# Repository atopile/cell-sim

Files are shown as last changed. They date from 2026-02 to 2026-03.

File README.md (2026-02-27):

# CellSim v2

Modular, rack-mountable battery cell simulator for BMS development and testing.

**Status:** In development — see [`docs/cellsim-v2-spec.md`](docs/cellsim-v2-spec.md) for the full specification.

## Overview

CellSim v2 uses a **backplane + card architecture**: a base board with a Raspberry Pi CM5 controller and gigabit Ethernet switch connects to up to ~20 plug-in cards, each carrying an STM32H723 MCU and 8 isolated cell channels.

### Key Specs (per channel)

| Parameter | Target |
|---|---|
| Output voltage | 0 – 6 V |
| Output current | 0 – 1 A |
| Voltage accuracy | ±1 mV (after calibration) |
| Update rate | 100 Hz |
| Kelvin sensing | Force + Sense, 2-wire/4-wire selectable |

### Card Types

- **Cell Card** — 8 isolated cell channels with Kelvin output
- **Thermistor Card** — 8 thermistor/NTC emulation channels
- Same backplane connector and form factor for both

## Repository Structure

```
elec/
  cell-card/      # Cell card electronics (base-card + cell/thermistor modules)
  backplane/      # Base board electronics (CM5, switches, power, fans)
  packages/       # Custom atopile packages (e.g. ADS1219)
firmware/
  card/           # Zephyr RTOS firmware for STM32H723 card MCU
software/
  src/cellsim/    # CM5 orchestration server (FastAPI) + Python client
mechanical/       # Enclosure, rack mount hardware
docs/             # Specification, diagrams
```

## Architecture

```
                    ┌─────────────────────────────────┐
                    │          Base Board              │
  Ethernet ────────►│  CM5  ──RGMII──►  RTL8305NB x5  │
  (uplink)          │  eth0            (cascaded GbE)  │
                    └──────────┬──────────────────────┘
                               │ 100M per port
               ┌───────────────┼───────────────┐
               ▼               ▼               ▼
         ┌──────────┐   ┌──────────┐   ┌──────────┐
         │ Card #0  │   │ Card #1  │   │ Card #N  │
         │ STM32H723│   │ STM32H723│   │ STM32H723│
         │ 8 cells  │   │ 8 cells  │   │ 8 cells  │
         └──────────┘   └──────────┘   └──────────┘
```

## Development

### Electronics (atopile)

The hardware is designed using [atopile](https://atopile.io/). Each board has its own `ato.yaml` build manifest.

### Firmware (Zephyr)

Card firmware uses [Zephyr RTOS](https://zephyrproject.org/) targeting the STM32H723. Development board: Nucleo-H723ZG.

### Software (Python)

The CM5 orchestration server is a FastAPI application. Install for development:

```bash
cd software
pip install -e ".[dev]"
cellsim  # starts the server on port 8000
```

## License

See [LICENSE](LICENSE).

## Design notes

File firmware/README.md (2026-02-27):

# CellSim Card Firmware

Zephyr RTOS firmware for the CellSim v2 cell card (STM32H723 + LAN8742A).

Each card manages 8 battery cell simulation channels. Cards communicate with a
central CM5 compute module over Ethernet: TCP for commands, UDP for 100 Hz
measurement streaming, mDNS for discovery.

## Prerequisites

- **Podman** (or Docker) — the entire toolchain runs in a container
- ~10 GB disk space for the Zephyr workspace (downloaded once, cached in a volume)

```bash
# Fedora / RHEL
sudo dnf install podman

# Ubuntu / Debian
sudo apt install podman

# Or use Docker — set CONTAINER_RT=docker in make commands
```

## Quick Start

```bash
cd firmware/

# First time: pull image + initialize west workspace (~5 min)
make setup

# Build firmware
make build
```

The output binary is at `build/zephyr/zephyr.bin`.

## Build Commands

| Command | Description |
|---|---|
| `make setup` | Pull Zephyr image + init west workspace (first time) |
| `make build` | Build firmware for nucleo_h723zg |
| `make clean` | Remove build artifacts |
| `make shell` | Interactive shell inside the build container |
| `make menuconfig` | Run Zephyr menuconfig (TUI Kconfig editor) |
| `make flash` | Flash via ST-Link (requires ST-Link on host) |
| `make help` | Show available targets |

Override the board: `make build BOARD=stm32h723zg_custom`

Use Docker instead of Podman: `make build CONTAINER_RT=docker`

## Project Structure

```
firmware/
├── Makefile                  # Build system (this file)
├── west.yml                  # West manifest — pins Zephyr v4.0.0
├── README.md                 # This file
├── build/                    # Build output (gitignored)
└── card/                     # Application source
    ├── CMakeLists.txt        # CMake build definition
    ├── prj.conf              # Zephyr Kconfig
    ├── boards/
    │   └── nucleo_h723zg.overlay  # Device tree overlay
    └── src/
        ├── main.c            # Entry point, slot ID, init sequence
        ├── network.c/.h      # TCP command server, UDP streaming, mDNS
        ├── self_test.c/.h    # Per-cell BIST (I2C probe, temp check)
        ├── watchdog.c/.h     # IWDG + CM5 heartbeat monitor
        └── health.c/.h       # MCU temp, Vrefint, input voltage (ADC3)
```

## Architecture

```
┌──────────────────────────────────────────────┐
│  main.c                                      │
│  ├─ read_slot_id()         GPIO decode       │
│  ├─ health_init()          ADC3 setup        │
│  ├─ watchdog_init()        IWDG + heartbeat  │
│  ├─ self_test_run()        I2C BIST all 8    │
│  └─ network_init()         mDNS + sockets    │
│       ├─ TCP cmd server    (thread, pri 7)   │
│       └─ UDP meas stream   (thread, pri 3)   │
│           └─ 100 Hz loop: ADC → pack → send  │
│              └─ watchdog_feed() per tick      │
└──────────────────────────────────────────────┘

I2C topology:
  I2C1 → TCA9548A → [ISO1640 → cell devices] × 4  (cells 0–3)
  I2C2 → TCA9548A → [ISO1640 → cell devices] × 4  (cells 4–7)

Per-cell devices (isolated side):
  MCP4725 ×2 (DAC: buck + LDO setpoint)
  ADS1219    (ADC: voltage + current)
  TCA6408    (GPIO: relay, enable, load switch)
  TMP117     (temperature)
```

## Configuration

### Kconfig (`card/prj.conf`)

Key options:
- `CONFIG_NET_DHCPV4=y` — DHCP for IP assignment
- `CONFIG_MDNS_RESPONDER=y` — mDNS advertisement
- `CONFIG_WATCHDOG=y` — Hardware IWDG
- MCUboot/MCUmgr options are commented out for initial builds

Edit interactively: `make menuconfig`

### Device Tree Overlay (`card/boards/nucleo_h723zg.overlay`)

Defines I2C buses, UART, ADC, watchdog, and Ethernet for the card PCB.
Pin assignments are placeholders pending final PCB layout.

### West Manifest (`west.yml`)

Pins Zephyr v4.0.0 with only the modules needed:
- `hal_stm32` — STM32H7 HAL
- `cmsis` — ARM CMSIS headers
- `mbedtls` — TLS stack
- `mcuboot` — Bootloader (for later OTA)
- `net-tools` — Networking utilities

## Flashing

### ST-Link (development)

Connect ST-Link to the card's SWD header, then:

```bash
make flash
```

### UART Bootloader (production — via CM5)

The CM5 can flash cards remotely using the STM32 ROM bootloader (AN3155):

1. CM5 selects the card via slot mux (CD74HC4067SM)
2. Asserts BOOT0 high + pulses NRST
3. Streams firmware over UART using the AN3155 protocol
4. Releases BOOT0, pulses NRST to boot into new firmware

### DFU over USB (if available)

```bash
dfu-util -a 0 -s 0x08000000 -D build/zephyr/zephyr.bin
```

## Troubleshooting

**`make setup` fails with permission error**
Podman's rootless mode needs `--userns=keep-id`. If you're using Docker, set
`CONTAINER_RT=docker`.

**`west update` hangs or fails**
The Zephyr tree is large. Ensure you have a stable internet connection.
The `--narrow -o=--depth=1` flags minimize download size.

**Build fails with "Zephyr not found"**
Run `make setup` first. The west workspace must be initialized before building.

**`CONFIG_ETH_STM32_HAL` warning**
If Zephyr renames this symbol, check `make menuconfig` under
Drivers → Ethernet for the current name.

**Flash fails: "No ST-Link detected"**
- Ensure the ST-Link is connected and powered
- Check `lsusb` for the ST-Link device
- The `--privileged` flag and `/dev/bus/usb` mount are needed for USB access

## Adapting for Other Projects

1. Copy `firmware/` to your project
2. Edit `west.yml` to add/remove Zephyr modules
3. Replace `card/` with your application
4. Update `BOARD` in the Makefile
5. Run `make setup && make build`

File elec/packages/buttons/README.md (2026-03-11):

# Buttons - Momentary Switches

Simple momentary switches that can be used to bridge connections in circuits.

## Usage

```ato
#pragma experiment("BRIDGE_CONNECT")
#pragma experiment("FOR_LOOP")

import Electrical
import ElectricPower
import Resistor

from "atopile/buttons/buttons.ato" import VerticalButton
from "atopile/buttons/buttons.ato" import HorizontalButton

module Usage:
    """
    Examples showing different ways to use buttons:
    1. Simple bridging connections
    2. Pullup configuration (button pulls to ground, resistor pulls to VCC)
    3. Pulldown configuration (button pulls to VCC, resistor pulls to ground)
    """

    # Power supply for pullup/pulldown examples
    power = new ElectricPower

    # === Example 1: Simple bridging ===
    btn_bridge = new VerticalButton
    signal_a = new Electrical
    signal_b = new Electrical

    # When button is pressed, signal_a connects to signal_b
    signal_a ~> btn_bridge ~> signal_b

    # === Example 2: Pullup configuration ===
    # Button pulls signal to ground when pressed, resistor pulls to VCC when released
    btn_pullup = new HorizontalButton
    pullup_resistor = new Resistor
    pullup_signal = new Electrical

    # Configure pullup resistor
    pullup_resistor.resistance = 10kohm +/- 5%
    pullup_resistor.package = "0402"

    # Connections: signal pulled high by resistor, pulled low by button
    power.hv ~> pullup_resistor ~> pullup_signal
    pullup_signal ~> btn_pullup ~> power.lv

    # === Example 3: Pulldown configuration ===
    # Button pulls signal to VCC when pressed, resistor pulls to ground when released
    btn_pulldown = new VerticalButton
    pulldown_resistor = new Resistor
    pulldown_signal = new Electrical

    # Configure pulldown resistor
    pulldown_resistor.resistance = 10kohm +/- 5%
    pulldown_resistor.package = "0402"

    # Connections: signal pulled low by resistor, pulled high by button
    power.lv ~> pulldown_resistor ~> pulldown_signal
    pulldown_signal ~> btn_pulldown ~> power.hv

```

## Contributing

Contributions to this package are welcome via pull requests on the GitHub repository.

## License

This atopile package is provided under the [MIT License](https://opensource.org/license/mit/).

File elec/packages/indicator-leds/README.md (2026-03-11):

# Indicator LEDs (0603) – Red/Green/Blue/Yellow/Yellow-Green/White

Convenience modules for single indicator LEDs with a correctly sized series resistor and bridgeable interface.

## Usage

```ato
#pragma experiment("BRIDGE_CONNECT")

import ElectricPower

from "atopile/indicator-leds/indicator-leds.ato" import LEDIndicatorRed
from "atopile/indicator-leds/indicator-leds.ato" import LEDIndicatorGreen

module Usage:
    """
    Minimal usage example for `indicator-leds`.
    Demonstrates direct power connection and bridge usage.
    """

    red_led = new LEDIndicatorRed
    green_led = new LEDIndicatorGreen

    # Direct power connection
    power = new ElectricPower
    power.voltage = 5V
    power ~ red_led.power
    power ~ green_led.power

```

## Contributing

Contributions are welcome! Feel free to open issues or pull requests.

## License

This package is provided under the [MIT License](https://opensource.org/license/mit/).

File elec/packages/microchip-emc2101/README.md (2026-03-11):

# Microchip EMC2101 Temperature Sensor and Fan Controller

A comprehensive driver for the Microchip EMC2101 temperature monitoring and PWM fan control IC. This package provides a complete atopile implementation for thermal management applications.

## Features

- **Internal Temperature Sensor**: ±2°C accuracy for local temperature monitoring
- **External Temperature Sensing**: Remote diode connection via DP/DN pins for CPU/GPU temperature monitoring
- **PWM Fan Control**: Precise fan speed control via dedicated FAN output pin
- **Tachometer/Alert**: Combined nALERT_TACH pin for thermal alerts and fan speed feedback
- **I2C/SMBus Interface**: Standard 3.3V communication interface (SMCLK/SMDATA)
- **Package**: MSOP-8 surface mount package
- **JLCPCB Part**: C626968 (EMC2101-R-ACZL-TR)

## Pin Configuration (MSOP-8)

1. **VDD** - Power supply (3.0V to 3.6V)
2. **DP** - External diode positive terminal
3. **DN** - External diode negative terminal
4. **FAN** - PWM fan drive output
5. **GND** - Ground
6. **nALERT_TACH** - Alert output / Tachometer input (shared pin)
7. **SMDATA** - I2C/SMBus Data
8. **SMCLK** - I2C/SMBus Clock

## Usage

```ato
#pragma experiment("TRAITS")
#pragma experiment("FOR_LOOP")
#pragma experiment("BRIDGE_CONNECT")

import ElectricLogic
import ElectricPower
import I2C
from "atopile/microchip-emc2101/microchip-emc2101.ato" import Microchip_EMC2101

module Usage:
    """
    Minimal usage example for microchip-emc2101.
    Demonstrates how to use the EMC2101 temperature sensor and fan controller
    in a typical thermal management application with MSOP-8 package.
    """

    # Power supply
    power_3v3 = new ElectricPower
    assert power_3v3.voltage within 3.2V to 3.4V

    # I2C bus for communication
    i2c_bus = new I2C
    assert i2c_bus.frequency within 100kHz to 400kHz

    # Fan control signal
    fan_pwm_signal = new ElectricLogic

    # EMC2101 temperature sensor and fan controller
    temp_controller = new Microchip_EMC2101

    # Connect power
    power_3v3 ~ temp_controller.power

    # Connect I2C bus
    i2c_bus ~ temp_controller.i2c

    # Connect fan PWM output
    fan_pwm_signal ~ temp_controller.pwm_out

```

### Optional Interfaces

The EMC2101 driver also provides optional interfaces for advanced features:

- **`alert_tach`**: Combined alert output and tachometer input (nALERT_TACH pin)
- **`temp_diode_p`** and **`temp_diode_n`**: External temperature diode connections for remote sensing

These interfaces can be connected when needed for more advanced thermal management applications.

## Key Interfaces

### Power Supply
- **Voltage**: 3.0V to 3.6V (3.3V typical)
- **Current**: Low power operation
- **Decoupling**: 100nF capacitor included

### I2C Communication
- **Default Address**: 0x4C (7-bit)
- **Speed**: Up to 400kHz (Fast-mode)
- **Pull-up Resistors**: 10kΩ included (optional - may be external)

### Temperature Sensing
- **Internal**: Built-in temperature sensor
- **External**: Remote diode sensing via DP/DN pins
- **Accuracy**: ±2°C typical

### Fan Control
- **Output**: PWM signal on FAN pin
- **Feedback**: Tachometer input on nALERT_TACH pin (shared with alert)
- **Alert**: Thermal limit violations on nALERT_TACH pin

## Contributing

Contributions are welcome! Feel free to open issues or pull requests.

## License

This package is provided under the [MIT License](https://opensource.org/license/mit).

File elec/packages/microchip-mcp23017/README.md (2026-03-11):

# Microchip MCP23017 – 16-bit I²C GPIO Expander

A declarative Atopile driver for the **Microchip MCP23017** 16-bit general-purpose I/O expander (QFN-28, LCSC part **C629439**).  The device provides two 8-bit GPIO banks over an I²C interface and operates from **1.8 V to 5.5 V**.

## Usage

```ato
#pragma experiment("MODULE_TEMPLATING")
#pragma experiment("BRIDGE_CONNECT")
#pragma experiment("FOR_LOOP")

# --- Standard library imports ---
import ElectricPower
import I2C

# --- Package import ---
from "atopile/microchip-mcp23017/microchip-mcp23017.ato" import Microchip_MCP23017

module Usage:
    """
    Minimal usage example for `microchip-mcp23017`.
    Powers the MCP23017 from a shared 3 V 3 rail and places it on an I²C bus
    running at the default 7-bit address (0x20).
    """

    # Power rail (3.3 V)
    power_3v3 = new ElectricPower
    power_3v3.voltage = 3.3V

    # I²C bus
    i2c_bus = new I2C

    # Expander instance
    expander = new Microchip_MCP23017

    # Connect required interfaces
    power_3v3 ~ expander.power
    power_3v3 ~ i2c_bus.scl.reference
    power_3v3 ~ i2c_bus.sda.reference

    i2c_bus ~ expander.i2c

    # (Optional) Explicitly set the expander address – defaults to 0x20
    expander.i2c.address = 0x20

```

## Contributing

Contributions are welcome! Feel free to open an issue or pull request—please ensure the `usage` build target passes (`ato build usage`).

## License

This package is provided under the [MIT License](https://opensource.org/license/mit/).

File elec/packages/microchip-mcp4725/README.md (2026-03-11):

# Microchip MCP4725 DAC

## Usage

```ato
import ElectricPower
import I2C

from "atopile/microchip-mcp4725/microchip-mcp4725.ato" import Microchip_MCP4725_driver

module Usage:
    """Minimal example for the Microchip MCP4725 DAC."""

    # DAC
    dac = new Microchip_MCP4725_driver

    # 3V3 power supply
    power = new ElectricPower
    power.voltage = 3.3V
    power ~ dac.power

    # I²C bus
    i2c = new I2C
    i2c ~ dac.i2c
```

## Contributing

Contributions to this package are welcome via pull requests on the GitHub repository.

## License

This atopile package is provided under the [MIT License](https://opensource.org/license/mit/).

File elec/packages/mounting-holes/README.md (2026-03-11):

# Mounting Holes

Various mounting holes for PCB mechanical attachment.

## Supported Sizes

- M2 (2.2mm hole)
- M2.5 (2.7mm hole)
- M3 (3.2mm hole)
- M4 (4.3mm hole)
- M5 (5.3mm hole)
- M6 (6.4mm hole)
- M8 (8.4mm hole)

## Supported Pad Types

- No Pad (no electrical contact)
- Pad (standard pad)
- Pad_TopBottom (pads on both sides)
- Pad_TopOnly (pad on top layer only)
- Pad_Via (pad with vias for thermal/electrical connection)

## Usage

```ato
from "atopile/mounting-holes/mounting-holes.ato" import MountingHole_2_2_M2
from "atopile/mounting-holes/mounting-holes.ato" import MountingHole_2_2_M2_Pad
from "atopile/mounting-holes/mounting-holes.ato" import MountingHole_2_2_M2_Pad_TopBottom
from "atopile/mounting-holes/mounting-holes.ato" import MountingHole_2_2_M2_Pad_TopOnly
from "atopile/mounting-holes/mounting-holes.ato" import MountingHole_2_2_M2_Pad_Via
from "atopile/mounting-holes/mounting-holes.ato" import MountingHole_2_7_M2_5
from "atopile/mounting-holes/mounting-holes.ato" import MountingHole_2_7_M2_5_Pad
from "atopile/mounting-holes/mounting-holes.ato" import MountingHole_2_7_M2_5_Pad_TopBottom
from "atopile/mounting-holes/mounting-holes.ato" import MountingHole_2_7_M2_5_Pad_TopOnly
from "atopile/mounting-holes/mounting-holes.ato" import MountingHole_2_7_M2_5_Pad_Via
from "atopile/mounting-holes/mounting-holes.ato" import MountingHole_3_2_M3
from "atopile/mounting-holes/mounting-holes.ato" import MountingHole_3_2_M3_Pad
from "atopile/mounting-holes/mounting-holes.ato" import MountingHole_3_2_M3_Pad_TopBottom
from "atopile/mounting-holes/mounting-holes.ato" import MountingHole_3_2_M3_Pad_TopOnly
from "atopile/mounting-holes/mounting-holes.ato" import MountingHole_3_2_M3_Pad_Via
from "atopile/mounting-holes/mounting-holes.ato" import MountingHole_4_3_M4
from "atopile/mounting-holes/mounting-holes.ato" import MountingHole_4_3_M4_Pad
from "atopile/mounting-holes/mounting-holes.ato" import MountingHole_4_3_M4_Pad_TopBottom
from "atopile/mounting-holes/mounting-holes.ato" import MountingHole_4_3_M4_Pad_TopOnly
from "atopile/mounting-holes/mounting-holes.ato" import MountingHole_4_3_M4_Pad_Via
from "atopile/mounting-holes/mounting-holes.ato" import MountingHole_5_3_M5
from "atopile/mounting-holes/mounting-holes.ato" import MountingHole_5_3_M5_Pad
from "atopile/mounting-holes/mounting-holes.ato" import MountingHole_5_3_M5_Pad_TopBottom
from "atopile/mounting-holes/mounting-holes.ato" import MountingHole_5_3_M5_Pad_TopOnly
from "atopile/mounting-holes/mounting-holes.ato" import MountingHole_5_3_M5_Pad_Via
from "atopile/mounting-holes/mounting-holes.ato" import MountingHole_6_4_M6
from "atopile/mounting-holes/mounting-holes.ato" import MountingHole_6_4_M6_Pad
from "atopile/mounting-holes/mounting-holes.ato" import MountingHole_6_4_M6_Pad_TopBottom
from "atopile/mounting-holes/mounting-holes.ato" import MountingHole_6_4_M6_Pad_TopOnly
from "atopile/mounting-holes/mounting-holes.ato" import MountingHole_6_4_M6_Pad_Via
from "atopile/mounting-holes/mounting-holes.ato" import MountingHole_8_4_M8
from "atopile/mounting-holes/mounting-holes.ato" import MountingHole_8_4_M8_Pad
from "atopile/mounting-holes/mounting-holes.ato" import MountingHole_8_4_M8_Pad_TopBottom
from "atopile/mounting-holes/mounting-holes.ato" import MountingHole_8_4_M8_Pad_TopOnly
from "atopile/mounting-holes/mounting-holes.ato" import MountingHole_8_4_M8_Pad_Via

module Usage:
    mountinghole_2_2_m2 = new MountingHole_2_2_M2
    mountinghole_2_2_m2_pad = new MountingHole_2_2_M2_Pad
    mountinghole_2_2_m2_pad_topbottom = new MountingHole_2_2_M2_Pad_TopBottom
    mountinghole_2_2_m2_pad_toponly = new MountingHole_2_2_M2_Pad_TopOnly
    mountinghole_2_2_m2_pad_via = new MountingHole_2_2_M2_Pad_Via
    mountinghole_2_7_m2_5 = new MountingHole_2_7_M2_5
    mountinghole_2_7_m2_5_pad = new MountingHole_2_7_M2_5_Pad
    mountinghole_2_7_m2_5_pad_topbottom = new MountingHole_2_7_M2_5_Pad_TopBottom
    mountinghole_2_7_m2_5_pad_toponly = new MountingHole_2_7_M2_5_Pad_TopOnly
    mountinghole_2_7_m2_5_pad_via = new MountingHole_2_7_M2_5_Pad_Via
    mountinghole_3_2_m3 = new MountingHole_3_2_M3
    mountinghole_3_2_m3_pad = new MountingHole_3_2_M3_Pad
    mountinghole_32m3padtopbottom = new MountingHole_3_2_M3_Pad_TopBottom
    mountinghole_32m3padtoponly = new MountingHole_3_2_M3_Pad_TopOnly
    mountinghole_32m3padvia = new MountingHole_3_2_M3_Pad_Via
    mountinghole_43m4 = new MountingHole_4_3_M4
    mountinghole_43m4pad = new MountingHole_4_3_M4_Pad
    mountinghole_43m4padtopbottom = new MountingHole_4_3_M4_Pad_TopBottom
    mountinghole_43m4padtoponly = new MountingHole_4_3_M4_Pad_TopOnly
    mountinghole_43m4padvia = new MountingHole_4_3_M4_Pad_Via
    mountinghole_53m5 = new MountingHole_5_3_M5
    mountinghole_53m5pad = new MountingHole_5_3_M5_Pad
    mountinghole_53m5padtopbottom = new MountingHole_5_3_M5_Pad_TopBottom
    mountinghole_53m5padtoponly = new MountingHole_5_3_M5_Pad_TopOnly
    mountinghole_53m5padvia = new MountingHole_5_3_M5_Pad_Via
    mountinghole_64m6 = new MountingHole_6_4_M6
    mountinghole_64m6pad = new MountingHole_6_4_M6_Pad
    mountinghole_64m6padtopbottom = new MountingHole_6_4_M6_Pad_TopBottom
    mountinghole_64m6padtoponly = new MountingHole_6_4_M6_Pad_TopOnly
    mountinghole_64m6padvia = new MountingHole_6_4_M6_Pad_Via
    mountinghole_84m8 = new MountingHole_8_4_M8
    mountinghole_84m8pad = new MountingHole_8_4_M8_Pad
    mountinghole_84m8padtopbottom = new MountingHole_8_4_M8_Pad_TopBottom
    mountinghole_84m8padtoponly = new MountingHole_8_4_M8_Pad_TopOnly
    mountinghole_84m8padvia = new MountingHole_8_4_M8_Pad_Via

    mountinghole_2_2_m2_pad.contact ~ mountinghole_2_2_m2_pad_topbottom.contact
```

## Contributing

Contributions to this package are welcome via pull requests on the GitHub repository.

## License

This atopile package is provided under the [MIT License](https://opensource.org/license/mit/).

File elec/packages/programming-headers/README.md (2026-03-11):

# ARM Cortex Programming Headers

Collection of ARM Cortex debug headers that wire JTAG and SWD pinouts for common connector formats, including 2.54mm box headers and Tag-Connect footprints. The modules expose shared JTAG and SWD interfaces so you can drop in the connector that fits your target or programming cable.

## Usage

```ato
from "atopile/programming-headers/programming-headers.ato" import HDR_2_54mm_10pin_ARM_Cortex
from "atopile/programming-headers/programming-headers.ato" import IDC_2_54mm_10pin_ARM_Cortex
from "atopile/programming-headers/programming-headers.ato" import IDC_2_54mm_20pin_ARM
from "atopile/programming-headers/programming-headers.ato" import TC2050_ARM_Cortex

module Usage:
    hdr_2_54mm_10pin_arm_cortex = new HDR_2_54mm_10pin_ARM_Cortex
    idc_2_54mm_10pin_arm_cortex = new IDC_2_54mm_10pin_ARM_Cortex
    idc_2_54mm_20pin_arm = new IDC_2_54mm_20pin_ARM
    tc2050_arm_cortex = new TC2050_ARM_Cortex

```

## Contributing

Contributions are welcome! Feel free to open issues or pull requests.

## License

This package is provided under the [MIT License](mdc:packages/packages/packages/https:/opensource.org/license/mit).

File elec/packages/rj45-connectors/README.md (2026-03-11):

# RJ45 Connectors

## Usage

```ato
#pragma experiment("BRIDGE_CONNECT")
#pragma experiment("FOR_LOOP")
#pragma experiment("TRAITS")

import Electrical
import ElectricLogic
import ElectricPower
import Ethernet

from "atopile/rj45-connectors/rj45-connectors.ato" import RJ45_Vertical_SMD
from "atopile/rj45-connectors/rj45-connectors.ato" import RJ45_Horizontal_TH_Magnetics
from "atopile/rj45-connectors/rj45-connectors.ato" import RJ45_Recessed_SMD
from "atopile/rj45-connectors/rj45-connectors.ato" import RJ45_Horizontal_TH_Magnetics_8Port
from "atopile/rj45-connectors/rj45-connectors.ato" import RJ45_Horizontal_SMD_Magnetics

module Usage:
    """
    Usage examples for RJ45 connectors package.

    Shows how to use both the vertical SMD connector (without magnetics)
    and the horizontal through-hole connector (with integrated magnetics).
    """

    # --- Power supply for logic references ---
    power_3v3 = new ElectricPower
    assert power_3v3.voltage within 3.3V +/- 5%

    # --- Example 1: Vertical SMD connector (no magnetics) ---
    rj45_vertical = new RJ45_Vertical_SMD

    # Connect Ethernet interface power reference
    rj45_vertical.ethernet.led_link.reference ~ power_3v3
    rj45_vertical.ethernet.led_speed.reference ~ power_3v3

    # Connect shield to ground
    rj45_vertical.shield ~ power_3v3.lv

    # --- Example 2: Horizontal TH connector with magnetics ---
    rj45_horizontal = new RJ45_Horizontal_TH_Magnetics

    # Connect Ethernet interface power reference
    rj45_horizontal.ethernet.led_link.reference ~ power_3v3
    rj45_horizontal.ethernet.led_speed.reference ~ power_3v3

    # Connect shield to ground
    rj45_horizontal.shield ~ power_3v3.lv

    # --- Example 3: Horizontal SMD connector with magnetics (HCTL HC632701A-M906-A) ---
    rj45_horizontal_smd = new RJ45_Horizontal_SMD_Magnetics
    rj45_horizontal_smd.ethernet.led_link.reference ~ power_3v3
    rj45_horizontal_smd.ethernet.led_speed.reference ~ power_3v3
    rj45_horizontal_smd.shield ~ power_3v3.lv

    # --- Example connections to external circuits ---
    # For the magnetics connector, you can connect directly to an Ethernet PHY:
    # phy.ethernet ~ rj45_horizontal.ethernet
    # For the vertical SMD, you would typically need external transformers

    rj45_recessed = new RJ45_Recessed_SMD
    rj45_recessed.ethernet.led_link.reference ~ power_3v3
    rj45_recessed.ethernet.led_speed.reference ~ power_3v3

    # Connect shield to ground
    rj45_recessed.shield ~ power_3v3.lv

    rj45_8port = new RJ45_Horizontal_TH_Magnetics_8Port
    # Connect shield to ground
    rj45_8port.shield ~ power_3v3.lv
```

## Contributing

Contributions are welcome! Feel free to open issues or pull requests.

## License

This package is provided under the [MIT License](https://opensource.org/license/mit).

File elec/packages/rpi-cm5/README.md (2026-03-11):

# Raspberry Pi Compute Module 5 (CM5)

## Usage

```ato
from "atopile/rpi-cm5/rpi-cm5.ato" import RPI_CM5

import ElectricPower

module Usage:
    """Usage example for the Raspberry Pi CM5 module"""

    cm5 = new RPI_CM5

    power_5v = new ElectricPower
    power_5v ~ cm5.power_5v

```

## Overview

This package provides the necessary components and interfaces to integrate the Raspberry Pi Compute Module 5 into your hardware designs using atopile.

## Contributing

Contributions to this package are welcome via pull requests on the GitHub repository.

## License

This `rpi-cm5` atopile package is provided under the [MIT License](https://opensource.org/license/mit/).

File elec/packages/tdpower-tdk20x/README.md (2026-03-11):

# TDPOWER TDK20 20W Isolated DC-DC Converter

## Usage

```ato
#pragma experiment("BRIDGE_CONNECT")

import ElectricPower
from "atopile/tdpower-tdk20x/tdpower-tdk20x.ato" import TDPOWER_TDK20_driver

module Usage:
    # Create converter (default 24V in, 24V out)
    converter = new TDPOWER_TDK20_driver

    # Create power rails
    power_in = new ElectricPower
    power_out = new ElectricPower

    # connect power to converter
    power_in ~ converter.power_in
    converter.power_out ~ power_out

```

## Contributing

Contributions to this package are welcome via pull requests on the GitHub repository.

## License

This atopile package is provided under the [MIT License](https://opensource.org/license/mit/).

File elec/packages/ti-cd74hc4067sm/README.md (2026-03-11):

# TI CD74HC4067SM 16-Channel Analog Multiplexer/Demultiplexer

Atopile driver for the TI CD74HC4067SM 16-Channel Analog Multiplexer/Demultiplexer.

The CD74HC4067SM is a 16-channel analog multiplexer/demultiplexer with 4 select lines.

## Features

- 16-channel analog multiplexer/demultiplexer
- 4 bit select lines
- 16 inputs/output
- 1 input/output

## Usage

```ato
#pragma experiment("FOR_LOOP")
#pragma experiment("TRAITS")

# --- Standard library imports ---
import ElectricPower
import has_part_removed

# --- Package import ---
from "atopile/ti-cd74hc4067sm/ti-cd74hc4067sm.ato" import TI_CD74HC4067SM

module FakeMCU:
    """
    Fake MCU to control the multiplexer.
    """
    power = new ElectricPower
    gpio = new ElectricLogic[5]

    trait has_part_removed

module Usage:
    """
    Minimal usage example for the `TI_CD74HC4067SM` 16-Channel Analog Multiplexer/Demultiplexer.
    """

    multiplexer = new TI_CD74HC4067SM
    mcu = new FakeMCU

    some_logic = new ElectricLogic

    power = new ElectricPower
    power.voltage = 5V +/- 5%

    multiplexer.power ~ power
    mcu.power ~ power

    multiplexer.selects[0].line ~ mcu.gpio[0].line
    multiplexer.selects[1].line ~ mcu.gpio[1].line
    multiplexer.selects[2].line ~ mcu.gpio[2].line
    multiplexer.selects[3].line ~ mcu.gpio[3].line

    multiplexer.common.line ~ mcu.gpio[4].line

    multiplexer.ios[0].line ~ power.lv
    multiplexer.ios[1].line ~ power.hv
    multiplexer.ios[2] ~ some_logic

```

## Contributing

Contributions are welcome! Please open an issue or pull request and ensure the `usage` build target passes (`ato build usage`).

## License

This package is provided under the [MIT License](https://opensource.org/license/mit/).

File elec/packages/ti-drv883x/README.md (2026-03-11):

# Texas Instruments DRV8837/DRV8838 H-Bridge Motor Drivers

Low-voltage H-bridge motor drivers for brushed DC motors.

- **DRV8837**: IN0/IN1 control interface
- **DRV8838**: PH/EN (Phase/Enable) control interface

## Features

- Logic voltage: 1.8V to 7V
- Motor voltage: 0V to 11V
- Integrated decoupling capacitors
- Sleep control for low-power mode

## Usage

```ato
#pragma experiment("TRAITS")
#pragma experiment("BRIDGE_CONNECT")
#pragma experiment("MODULE_TEMPLATING")

import ElectricPower
import ElectricLogic
import Electrical
import can_bridge_by_name

from "atopile/ti-drv883x/ti-drv883x.ato" import TI_DRV8837
from "atopile/ti-drv883x/ti-drv883x.ato" import TI_DRV8838

module FakeMotor:
    """
    Mock motor device for testing
    """
    unnamed = new Electrical[2]
    trait can_bridge_by_name<input_name = "unnamed[0]", output_name = "unnamed[1]">

module Usage:
    """
    Example usage of the TI_DRV8837 and TI_DRV8838 H-bridge (motor) drivers
    """

    power_3v3 = new ElectricPower
    power_3v3.voltage = 3.3V +/- 5%
    power_6v = new ElectricPower
    power_6v.voltage = 6V +/- 5%

    # some mock gpio from e.g. a gpio expander
    gpio_0 = new ElectricLogic
    gpio_1 = new ElectricLogic
    gpio_3 = new ElectricLogic

    motor_driver_in0_in1 = new TI_DRV8837
    motor_driver_in0_in1.logic_power ~ power_3v3
    motor_driver_in0_in1.motor_power ~ power_6v
    motor_driver_in0_in1.sleep ~ gpio_3
    motor_driver_in0_in1.inputs[0] ~ gpio_0
    motor_driver_in0_in1.inputs[1] ~ gpio_1
    motor_0 = new FakeMotor
    motor_driver_in0_in1.motor_outs[0] ~> motor_0 ~> motor_driver_in0_in1.motor_outs[1]

    motor_driver_ph_en = new TI_DRV8838
    motor_driver_ph_en.logic_power ~ power_3v3
    motor_driver_ph_en.motor_power ~ power_6v
    motor_driver_ph_en.sleep ~ gpio_3
    motor_driver_ph_en.phase ~ gpio_0
    motor_driver_ph_en.enable ~ gpio_1
    motor_1 = new FakeMotor
    motor_driver_ph_en.motor_outs[0] ~> motor_1 ~> motor_driver_ph_en.motor_outs[1]

```

### DRV8837 Truth Table (IN0/IN1)

| nSLEEP | IN1 | IN2 | OUT1 | OUT2 | Function |
| --- | --- | --- | ---- | ---- | --- |
| 0 | X | X | Z | Z | Coast |
| 1 | 0 | 0 | Z | Z | Coast |
| 1 | 0 | 1 | L | H | Reverse  |
| 1 | 1 | 0 | H | L | Forward  |
| 1 | 1 | 1 | L | L | Brake |

### DRV8838 Truth Table (PH/EN)

| nSLEEP | PH  | EN  | OUT1 | OUT2 | Function |
| --- | --- | --- | ---- | ---- | --- |
| 0 | X | X | Z | Z | Coast |
| 1 | X | 0 | L | L | Brake |
| 1 | 1 | 1 | L | H | Reverse  |
| 1 | 0 | 1 | H | L | Forward  |

## Contributing

Contributions to this package are welcome via pull requests on the GitHub repository.

## License

This atopile package is provided under the [MIT License](https://opensource.org/license/mit/).

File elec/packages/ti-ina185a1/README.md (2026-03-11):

# TI INA185A1 Current Sense Amplifier

Atopile driver for the TI INA185A1 zero-drift, bidirectional current sense amplifier.

## Usage

```ato
#pragma experiment("TRAITS")

# --- Standard library imports ---
import ElectricPower
import ElectricSignal
import Resistor

# --- Package import ---
from "atopile/ti-ina185a1/ti-ina185a1.ato" import TI_INA185A1

module Usage:
    """
    Minimal usage example for the TI INA185A1 current sense amplifier.
    """
    amplifier = new TI_INA185A1
    power_to_load = new ElectricPower

    # fake analog signal output
    amplified_signal = new ElectricSignal

    # System rails
    system_3v3 = new ElectricPower
    system_3v3.voltage = 3.3V +/- 5%

    load_power = new ElectricPower
    load_power.voltage = 12V +/- 5%

    # Shunt resistor for current sensing
    shunt = new Resistor
    shunt.resistance = 10mohm +/- 1%
    shunt.package = "1206"

    # Power the amplifier
    amplifier.power ~ system_3v3

    # connect the output reference to ground for 0 offset
    amplifier.ref.line ~ system_3v3.lv

    # connect amplifier output
    amplified_signal ~ amplifier.output

    # connect the load and shunt and grounds
    load_power.hv ~> shunt ~> power_to_load.hv
    load_power.lv ~ power_to_load.lv
    load_power.lv ~ system_3v3.lv
    amplifier.input.p.line ~> shunt ~> amplifier.input.n.line

```

## Contributing

Contributions are welcome! Please open an issue or pull request and ensure the `usage` build target passes (`ato build usage`).

## License

This package is provided under the [MIT License](https://opensource.org/license/mit/).

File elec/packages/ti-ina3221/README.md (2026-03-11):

# Texas Instruments INA3221 Triple-Channel Current & Power Monitor

The INA3221 is a triple-channel, high-side current and power monitor with an I2C and SMBus-compatible interface from Texas Instruments. This device is ideal for monitoring multiple power rails in battery-powered systems, servers, and other applications requiring precise current measurement.

## Features

- **Triple-channel high-side current sensing**
- **Wide supply voltage range**: 2.7V to 5.5V (IC supply)
- **Bus voltage monitoring**: 0V to 26V per channel
- **High accuracy**: ±0.1% gain error (typical)
- **I2C interface** with configurable address (0x40-0x43)
- **Programmable conversion times** and averaging modes
- **Alert functionality** with warning and critical thresholds
- **Low power consumption**: 350µA typical supply current
- **Operating temperature**: -40°C to +125°C
- **16-bit ADC** with programmable conversion time
- **Compact package**: QFN-16 (4mm × 4mm)

## Usage

```ato
#pragma experiment("TRAITS")
#pragma experiment("BRIDGE_CONNECT")

import ElectricPower
import I2C
import has_part_removed

from "atopile/ti-ina3221/ti-ina3221.ato" import TI_INA3221

module Sink:
    """
    mock sink device for testing
    """
    power = new ElectricPower
    trait has_part_removed

module Usage:
    """
    Minimal usage example for TI INA3221 triple-channel current and power monitor.
    Shows how to connect power supply, I2C bus, and three monitored power rails.
    """

    # Create current monitor instance
    current_monitor = new TI_INA3221
    sinks = new Sink[3]

    # Main power supply for the IC (3.3V or 5V)
    power_3v3 = new ElectricPower
    power_3v3.voltage = 3.3V +/- 5%

    # External I2C bus
    i2c_bus = new I2C

    # Example monitored power rails
    power_5v = new ElectricPower
    power_5v.voltage = 5V +/- 5%

    # Connect interfaces
    power_3v3 ~ current_monitor.power
    i2c_bus ~ current_monitor.i2c

    # Connect monitored channels (bridgeable)
    power_5v ~> current_monitor.channels[0] ~> sinks[0].power
    power_5v ~> current_monitor.channels[1] ~> sinks[1].power
    power_5v ~> current_monitor.channels[2] ~> sinks[2].power

    # Set I2C address (default 0x40 with A0 pin low)
    current_monitor.i2c.address = 0x40

```

## Technical Specifications

- **Supply Voltage (VS)**: 2.7V to 5.5V
- **Bus Voltage Range**: 0V to 26V per channel
- **Common-Mode Voltage**: 0V to 26V
- **I2C Address**: 0x40 (default), 0x41, 0x42, 0x43 (configurable via A0 pin)
- **Supply Current**: 350µA (typical)
- **Shunt Voltage Range**: ±163.8mV
- **ADC Resolution**: 16-bit (13-bit effective)
- **Conversion Time**: 140µs to 8.244ms (programmable)
- **I2C Speed**: Up to 2.94 MHz
- **Package**: QFN-16 (4mm × 4mm)

## I2C Address Configuration

The INA3221 supports four different I2C addresses controlled by the A0 pin:

| A0 Connection | I2C Address | Description |
|---|---|---|
| GND | 0x40 | Default configuration |
| VS | 0x41 | Connected to supply voltage |
| SDA | 0x42 | Connected to I2C data line |
| SCL | 0x43 | Connected to I2C clock line |

## Pin Configuration

| Pin | Name | Description |
|-----|---|---|
| 1 | IN_3 | Channel 3 Input (-) |
| 2 | INplus3 | Channel 3 Input (+) |
| 3 | GND | Ground |
| 4 | VS | Supply Voltage |
| 5 | A0 | Address Select Pin |
| 6 | SCL | I2C Serial Clock |
| 7 | SDA | I2C Serial Data |
| 8 | WARNING | Warning Alert Output |
| 9 | CRITICAL  | Critical Alert Output |
| 10  | PV | Pullup Voltage |
| 11  | IN_1 | Channel 1 Input (-) |
| 12  | INplus1 | Channel 1 Input (+) |
| 13  | TC | Timing Control |
| 14  | IN_2 | Channel 2 Input (-) |
| 15  | INplus2 | Channel 2 Input (+) |
| 16  | VPU | Internal Pullup |
| 17  | PAD | Exposed Pad (Ground) |

## Current Sensing Configuration

The INA3221 includes three `Channel` modules, each with integrated shunt resistors:

### Channel Module Features
- **Bridgeable design**: Use `~>` to connect power rails through the current sensor
- **Integrated shunt resistor**: Default 100mΩ ±1% (configurable)
- **Power flow**: `power_in ~> shunt ~> power_out`
- **Differential sensing**: Connected to INA3221 via `sense.p` and `sense.n`
- **Bus voltage monitoring**: 0V to 26V per channel

### Shunt Resistor Selection
- **Shunt voltage range**: ±163.8mV
- **Typical shunt values**: 0.1Ω, 0.01Ω, 0.001Ω
- **Current calculation**: I = V_shunt / R_shunt
- **Power calculation**: P = V_bus × I

### Example Usage Patterns
```ato
# Direct monitoring (channel as bridge)
power_source ~> current_monitor.channels[0] ~> load

# Monitoring without load connection
power_rail ~ current_monitor.channels[1].power_in
# Load connects to channels[1].power_out separately
```

## Applications

- Battery management systems
- Server and datacenter power monitoring
- Industrial automation
- Automotive power management
- Solar power systems
- Multi-rail power supplies
- IoT device power profiling
- Power consumption analysis

## Alert Functions

- **WARNING**: Configurable threshold for bus voltage, shunt voltage, or power
- **CRITICAL**: Configurable threshold for bus voltage, shunt voltage, or power
- **Timing Control**: External conversion triggering
- **Conversion-ready flag**: Available via I2C status register

## Contributing

Contributions are welcome! Feel free to open issues or pull requests.

## License

This package is provided under the [MIT License](https://opensource.org/license/mit).

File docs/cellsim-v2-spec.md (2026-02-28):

# CellSim v2 — Specification & Architecture

**Status:** DRAFT v7
**Date:** 2026-02-27
**Branch:** `feature/cellsim-v2`

---

## 1. Overview

CellSim v2 is a modular, rack-mountable battery cell simulator for BMS development and testing. It uses a **backplane + card** architecture: a base board with a Raspberry Pi CM5 controller and gigabit Ethernet switch connects to up to 16 plug-in cards, each carrying an STM32H723 MCU and 8 isolated cell channels.

The software stack mirrors the proven Peak cellsim-48ch design (FastAPI REST server, device tree abstraction, async drivers, calibration system) but distributed across Ethernet rather than centralized I2C.

### 1.1 Design Goals

- **Modular card architecture:** GPU-style plug-in cards into a common backplane
- **Fully isolated:** Each cell has its own isolated DC-DC + I2C/SPI isolators (cells at different potentials)
- **Scalable:** 8 to 128 channels (up to 16 cards)
- **Kelvin sensing:** 4-wire (force + sense) per channel, software-switchable to 2-wire mode
- **Self-testable:** ADC verifies every DAC output; full BIST for every card
- **High update rate:** Up to 10 kHz measurement and control across all channels
- **Gigabit Ethernet backbone:** CM5 ↔ cards via on-backplane GbE switch
- **Thermal management:** Fan controller on base board, temperature sensors on every card
- **OTA firmware updates:** CM5 pushes firmware to cards over Ethernet
- **Package-first:** Maximize atopile registry packages, minimize custom components
- **Peak-compatible software:** FastAPI + device tree + async drivers + calibration

### 1.2 Key Specs (per channel)

| Parameter | Target | Notes |
|---|---|---|
| Output voltage range | 0 – 5 V | Programmable |
| Output current | 0 – 1 A | Continuous, with current sensing |
| Voltage resolution | < 0.1 mV | 24-bit ADC (ADS131M04, ~20 noise-free bits) |
| Voltage accuracy | ±1 mV | After calibration |
| Current measurement | ±0.1 mA | 24-bit ADC |
| Update rate | up to 10 kHz | Measurement; control loop 1–10 kHz |
| Open-circuit simulation | Yes | Output relay per channel |
| Kelvin sensing | Yes | Force + Sense, 2-wire/4-wire selectable |
| Channels per card | 8 | |
| Max cards per system | 16 | Backplane limited |

### 1.3 Card Types

| Card Type | Description |
|---|---|
| **Cell Card** | 8 isolated cell channels (0–5 V, 0–1 A) with Kelvin output |
| **Thermistor Card** | Same form factor, thermistor/NTC emulation outputs |
| *(future)* | Other emulation cards sharing the same backplane |

---

## 2. System Architecture

### 2.1 Physical Topology

```
┌──────────────────────────────────────────────────────────────────────────┐
│                         RACK MOUNT ENCLOSURE (19", 2U/3U)                │
│                                                                          │
│  FRONT PANEL                                                             │
│  ┌────────────────────────────────────────────────────────────────────┐  │
│  │ [E-STOP] [OLED] [Status LEDs] [RJ45 Uplink] [USB-C CM5] [Fan %] │  │
│  └────────────────────────────────────────────────────────────────────┘  │
│                                                                          │
│  ┌────────────────────────────────────────────────────────────────────┐  │
│  │                      BASE BOARD (BACKPLANE)                        │  │
│  │                                                                    │  │
│  │  ┌──────┐  ┌────────────┐  ┌────────────────────────────────────┐ │  │
│  │  │ CM5  │──│ GbE Switch │──│  Card Slots (×16)                  │ │  │
│  │  │      │  │ (RTL8305NB │  │  ┌──┐┌──┐┌──┐┌──┐┌──┐     ┌──┐   │ │  │
│  │  │      │  │  cascade)  │  │  │0 ││1 ││2 ││3 ││4 │ ... │15│   │ │  │
│  │  └──────┘  └────────────┘  │  └──┘└──┘└──┘└──┘└──┘     └──┘   │ │  │
│  │                             └────────────────────────────────────┘ │  │
│  │  ┌──────────┐  ┌───────────────┐                                  │  │
│  │  │ Fan Ctrl │  │ Temp Sensors  │                                  │  │
│  │  │ (PWM)    │  │ (base board)  │                                  │  │
│  │  └──────────┘  └───────────────┘                                  │  │
│  └────────────────────────────────────────────────────────────────────┘  │
│                                                                          │
│  REAR PANEL                                                              │
│  ┌────────────────────────────────────────────────────────────────────┐  │
│  │ [IEC C14 Mains] [Card 0 Out][Card 1 Out]...[Card 15 Out]         │  │
│  └────────────────────────────────────────────────────────────────────┘  │
│                                                                          │
│  INTERNAL: Meanwell 24V PSU (e.g. LRS-350-24) + cooling fans            │
└──────────────────────────────────────────────────────────────────────────┘
```

### 2.2 Base Board (Backplane)

| Component | Function |
|---|---|
| **Raspberry Pi CM5** | Main controller — FastAPI server, card orchestration, firmware updates |
| **GbE Switch** | Cascaded RTL8305NB switches (proven in Hyperion) connecting CM5 ↔ all card slots |
| **Meanwell PSU** | Off-the-shelf enclosed 24V supply (IEC C14 mains input on rear panel) |
| **24V power bus** | Distributes 24V to each card slot via per-slot relay |
| **Per-slot power relays** | 16× Omron G5Q-1A4 DC24 (SPST-NO, 10A/30VDC), individually software-controlled via MCP23017 + N-FET. E-stop button cuts coil supply to all relays simultaneously. |
| **Per-slot current monitoring** | 7× INA3221 (3-ch each) behind TCA9548A mux — measures per-slot 24V current downstream of relay |
| **Bus power monitor** | INA228 on main 24V bus — total system current + power |
| **Fan controller** | PWM-driven fans, temperature-feedback closed loop |
| **Temperature sensors** | On base board + reported by each card |
| **Card slot connectors** | GPU-style edge connectors: Ethernet pairs + 24V + GND + slot ID bits + CAL traces |
| **Calibration mux** | 16× DPDT relays (one per slot), 2× TCA6408 GPIO expanders on CM5 I2C, banana jacks for external DMM |
| **E-Stop circuit** | Front panel NC mushroom-head button, series with relay coil supply — kills all 16 slot relays simultaneously |
| **OLED display** | System status (IP, card count, temps, fan speed) |
| **Uplink RJ45** | External network (front panel) |
| **USB-C** | CM5 debug/console (front panel) |

### 2.3 Cell Card (8-Channel)

Each card is a self-contained PCB that plugs into the backplane like a GPU. The card has **two tiers of galvanic isolation**:

1. **Card-level isolation (backplane ↔ card MCU domain):** An isolated 24V→24V DC-DC converter, a discrete Ethernet transformer, and a UART digital isolator create a fully isolated card domain. This allows stacking multiple cards for high-voltage configurations (up to ~1 kV theoretical).

2. **Per-cell isolation (card MCU domain ↔ each cell):** Each of the 8 cells has its own isolated DC-DC, I2C isolator, and SPI isolator. Cells stack in series (emulating an 8S battery), so cell 0's ground might be at 0 V while cell 7's ground is at ~40 V relative to the card domain.

```
                         CARD (plugs vertically into backplane)
┌───────────────────────────────────────────────────────────────────┐
│                                                                   │
│  BACKPLANE SIDE (non-isolated)                                    │
│  ═══════════════════════════════════════════════════════════      │
│  EDGE CONNECTOR (to backplane)                                    │
│  [Eth TX+/-] [Eth RX+/-] [24V×4] [GND×4] [ID0-3] [UART] [RST]  │
│  ═══════════════════════════════════════════════════════════      │
│       │            │            │                                  │
│       │     ┌──────┴──────┐    │                                  │
│       │     │ Eth Xfmr    │    │  ◄── Discrete Ethernet           │
│       │     │ (magnetics) │    │      transformer (galvanic iso)  │
│       │     └──────┬──────┘    │                                  │
│       │            │     ┌─────┴──────┐                           │
│       │            │     │ ISO DC-DC  │ ◄── 24V→24V isolated      │
│       │            │     │ (24V→24V)  │     (e.g. TDK20-24S24WH) │
│       │            │     └─────┬──────┘                           │
│       │            │           │                                  │
│  ┌────┴────┐       │    ┌──────┴──────┐                           │
│  │ UART    │       │    │ 24V_iso     │                           │
│  │ Isolator│       │    │    │        │                           │
│  └────┬────┘       │    │ TPSM84209  │ ◄── 24V→3.3V/5V buck      │
│       │            │    │ (24V→3.3V) │     for card electronics   │
│  ═════╪════════════╪════╪════════════╪════════════════════════    │
│  CARD ISOLATED DOMAIN  │            │                             │
│       │            │    │  3.3V_card │                             │
│  ┌────┴────────────┴────┴────────────┴─────────┐                  │
│  │ STM32H723 + LAN8742A PHY                    │                  │
│  │                                              │                  │
│  │  I2C1 ────→ TCA9548A ──→ Cells 0-7          │                  │
│  │              (8 channels, ISO1640 per cell)  │                  │
│  │                                              │                  │
│  │  SPI1 ────→ ISO7741 ×4 → Cells 0-3 ADC      │                  │
│  │  SPI2 ────→ ISO7741 ×4 → Cells 4-7 ADC      │                  │
│  │                                              │                  │
│  │  ADC  ────→ Input voltage sense, board temp  │                  │
│  │  GPIO ────→ Slot ID pins (from backplane)    │                  │
│  │  SWD  ────→ Debug header (optional)          │                  │
│  │  USB  ────→ USB-C (DFU fallback)             │                  │
│  └──────────────────────────────────────────────┘                  │
│       │                                                            │
│       │  ┌──────────────────────────────────────────────────┐      │
│       │  │  8× Isolated Cell Channels                       │      │
│       │  │  (each powered from 24V_iso via per-cell         │      │
│       │  │   isolated DC-DC, stacked in series like 8S)     │      │
│       │  │  ┌─────┐ ┌─────┐ ┌─────┐ ┌─────┐               │      │
│       │  │  │ C0  │ │ C1  │ │ C2  │ │ C3  │ (I2C1 + SPI1) │      │
│       │  │  └──┬──┘ └──┬──┘ └──┬──┘ └──┬──┘               │      │
│       │  │  ┌─────┐ ┌─────┐ ┌─────┐ ┌─────┐               │      │
│       │  │  │ C4  │ │ C5  │ │ C6  │ │ C7  │ (I2C1 + SPI2) │      │
│       │  │  └──┬──┘ └──┬──┘ └──┬──┘ └──┬──┘               │      │
│       │  └─────┼───────┼───────┼───────┼────────────────┘      │
│       │        │       │       │       │                       │
│  REAR CONNECTOR (to DUT)                                          │
│  [F0 S0] [F1 S1] [F2 S2] [F3 S3] [F4 S4] [F5 S5] [F6 S6]      │
│  [F7 S7] [GND_K] [GND_K_S]                                       │
└───────────────────────────────────────────────────────────────────┘
```

**Card-level isolation components:**

| Component | Function | Notes |
|---|---|---|
| **Isolated DC-DC (24V→24V)** | Galvanic isolation between backplane and card domain | e.g. TDPOWER TDK20-24S24WH (20W), proven in Peak 48ch design |
| **Discrete Ethernet transformer** | Isolates Ethernet PHY from backplane | Ethernet passes through backplane (not a separate RJ45 on the card) |
| **UART digital isolator** | Isolates UART for card programming/debug | Backplane routes UART to CM5 via slot mux for remote flash |
| **TPSM84209 buck** | 24V_iso → 3.3V (or 5V→3.3V) for MCU domain | 4.5–28V in, 2.5A, integrated inductor |

### 2.4 Multi-Bus Architecture (I2C + SPI)

The STM32H723 uses **I2C for control** (DACs, GPIO, temp) and **SPI for high-speed ADC** (ADS131M04):

**I2C bus (400 kHz Fast Mode) — control path:**

A single TCA9548A I2C mux provides 8 channels — one per cell. Each cell's I2C devices (DACs, GPIO expander, temp sensor) sit behind an ISO1640 isolator on the corresponding mux channel.

| Operation | Time per cell | Notes |
|---|---|---|
| TCA9548A mux switch | ~50 µs | 2-byte write |
| ISO1640 transparent | ~0 µs | Adds no delay |
| MCP4725 DAC write × 2 | ~200 µs | Buck + LDO setpoints |
| TCA6408 GPIO write | ~50 µs | Relay/enable states |
| **Per-cell I2C total** | **~300 µs** | ADC no longer on I2C |
| **8 cells sequential** | **~2.4 ms** | Single I2C bus |

**SPI bus (up to 25 MHz) — measurement path:**

| Operation | Time per cell | Notes |
|---|---|---|
| ADS131M04 read (4 channels) | ~10 µs | 24-bit × 4ch via SPI at 10 MHz |
| ISO7741 transparent | ~0 µs | 100 Mbps digital isolator |
| **Per-cell SPI total** | **~10 µs** | Simultaneous 4-ch, no mux |

**Combined cycle time (8 cells):**

| Path | Time | Rate |
|---|---|---|
| I2C control (DAC + GPIO) | ~2.4 ms | ~415 Hz (single bus, 8 cells sequential) |
| SPI measurement (ADC) | ~80 µs | **~12 kHz** (sequential scan, all 8 cells, 2 SPI buses) |
| Overhead + Ethernet | ~1 ms | Packet assembly, send |
| **Total (control + measure)** | **~3.5 ms** | **~285 Hz full loop** |
| **Measurement only** | **~1.1 ms** | **~900 Hz** (read all 8 cells) |

**Note:** At 32 kSPS/channel, the ADS131M04 produces data faster than the I2C control path can update DACs. The practical architecture is: ADC runs continuously at up to 32 kSPS, firmware reads at 1–10 kHz, DAC updates only when setpoint changes (event-driven, not every cycle). See §4.9.9 for SPI DAC upgrade path that eliminates the I2C bottleneck.

**Bus assignment:**
- **I2C1:** TCA9548A → Cells 0–7 (each behind ISO1640, mux channels 0–7) — DACs + GPIO + temp
- **SPI1:** Cells 0–3 ADC (each behind ISO7741) — via MISO mux (CD74HC4052)
- **SPI2:** Cells 4–7 ADC (each behind ISO7741) — via MISO mux (CD74HC4052)
- **I2C3:** (spare — on-card EEPROM, card-level temp sensor)

DMA-driven I2C and SPI transfers on the STM32H7 allow SPI buses to run in parallel with minimal CPU intervention. The single I2C bus handles the slow-changing control path (DAC setpoints only update when voltage target changes, not every cycle).

**SPI bus architecture per 4-cell group:**
```
STM32H723 SPIx
  ├── SCLK ──→ [to all 4 ISO7741 forward ch A]
  ├── MOSI ──→ [to all 4 ISO7741 forward ch B]
  ├── CS0..CS3 ──→ [to each ISO7741 forward ch C] (individual per cell)
  └── MISO ←── [CD74HC4052 2:1 mux] ←── 4× ISO7741 reverse ch
                     ↑ select via GPIO (2 bits)
```
Each cell's ISO7741 isolates the SPI signals across the galvanic barrier. The MISO return uses an analog mux (CD74HC4052) on the non-isolated side to avoid bus contention, selected in sync with the CS line.

**I2C bus speed analysis:**

The I2C bus is limited by the slowest components:
- STM32H723: 1 MHz Fm+ ✓
- TCA9548A mux: **400 kHz max** (weakest link — upgrade to NXP PCA9848 for 1 MHz if needed)
- ISO1640 isolator: 1.7 MHz ✓
- MCP4725 DAC: 3.4 MHz ✓
- TCA6408 GPIO: **400 kHz max** (upgrade to NXP PCAL6408A for 1 MHz if needed)

**Practical I2C limit: 400 kHz.** Sufficient for control path — the I2C path only handles slow-changing setpoints (DAC writes) and GPIO state changes, not high-speed measurement. The full 8-cell sequential scan takes ~2.4 ms, but in practice DAC updates are event-driven (only when setpoint changes), making the I2C bus lightly loaded.

**Why single I2C bus (changed from 2× I2C):** The TCA9548A has 8 channels, sufficient for all 8 cells. Two I2C buses provided only ~2× speedup for the control path (which is already not the bottleneck — SPI ADC measurement is the fast path). A single I2C bus simplifies routing, reduces MCU pin usage, and eliminates one TCA9548A. If higher control rates are needed, the SPI DAC upgrade path (§4.9.9) is the correct solution.

### 2.5 Per-Cell Architecture

Same proven isolated supply → buck → LDO topology from the 48ch design, uprated for 5 V / 1 A. Each cell is powered from the card's isolated 24V rail (24V_iso), NOT directly from the backplane:

```
24V_iso (from card-level isolated DC-DC)
  │
  ├── Per-cell Isolated DC-DC (24V → 12V, 3W) ── [CELL DOMAIN, floating]
  │   YLPTEC B2412S-3WR2 (C5369517)                    │
  │                                                      │
  │         ┌──── I2C Isolator (ISO1640) ────────────────┤ (DACs + GPIO + temp)
  │         ├──── SPI Isolator (ISO7741) ───────────────┤ (ADC)
  │         │                                            │
  │    (Card MCU domain)                          (Cell domain)
  │                                                      │
  │                                          ┌───────────┴───────────┐
  │                                          │  3.3V LDO (LDK220)   │
  │                                          │  12V → 3.3V          │
  │                                          │  (control rail)      │
  │                                          └───────────┬───────────┘
  │                                                      │
  │                                               Digital Buck
  │                                               (TPS563201, DAC-controlled)
  │                                               12V → ~5.5V variable
  │                                                      │
  │                                               Digital LDO
  │                                               (TLV75901, DAC-controlled)
  │                                               Buck out → 0–5V
  │                                                      │
  │                                              Current Sensor
  │                                               (INA185 + 50mΩ shunt)
  │                                                      │
  │                                               Output Relay (DPDT)
  │                                                   │      │
  │                                                FORCE    SENSE
  │                                                   │      │
  │                                              Kelvin output connector
  │
  │                                               [Temp Sensor (TMP117)]
  │                                               (on cell isolated side)
```

**All cells float.** Even cell 0 is isolated — cells stack in series to emulate an 8S battery pack. Cell 0 GND at ~0 V, cell 7 GND at up to ~40 V relative to the card domain.

**Per-cell I2C devices (on isolated side, behind ISO1640 + TCA9548A mux channel):**

| Device | Function | Bus | Speed | Self-test |
|---|---|-----|---|---|
| MCP4725 DAC | Buck voltage setpoint | I2C | 3.4 MHz | ADC reads buck output |
| MCP4725 DAC | LDO voltage setpoint | I2C | 3.4 MHz | ADC reads LDO output |
| TCA6408 GPIO | Relay, enable, load switch, 2/4-wire | I2C | 400 kHz | Read-back via ADC |
| **ADS131M04 ADC** | Voltage + current measurement (4ch) | **SPI** | 25 MHz | Verifies DAC outputs |

**ADC: ADS131M04 (24-bit, 4ch simultaneous, SPI)**

Upgraded from ADS1115 (16-bit, I2C) to ADS131M04 (24-bit, SPI). Key specs:
- 24-bit delta-sigma, **4 channels sampled simultaneously** (no mux — all channels every conversion)
- Up to **32 kSPS per channel** — enables 1–10 kHz control loop
- ~20 noise-free bits at 4 kSPS (gain=1)
- SPI interface (up to 25 MHz clock) — isolated via ISO7741 per cell
- Internal 1.2V reference only (no external VREF input); PGA gain = 1 → ±1.2V input range
- With 1:5 voltage dividers (see §4.2.8) for 0–5V input → ~10 µV resolution at signal → **well under 1 mV**
- JLCPCB: C2862562 (537 units in stock, **$1.83** — cheaper than ADS1219 at $7.82)
- Power: 3.3 mW total — lower than ADS1219 (~5 mW)

**SPI isolator: ISO7741FDBQR (4-ch digital isolator)**
- 3 forward channels (SCLK, MOSI, CS) + 1 reverse channel (MISO) — perfect SPI match
- 100 Mbps data rate per channel
- 5 kV reinforced isolation
- JLCPCB: C571196 ($0.44)
- Replaces I2C path for ADC only; ISO1640 still used for I2C devices (DACs, GPIO)

**ADS131M04 channel mapping:**

| ADC Channel | Measurement | Self-test for |
|---|---|---|
| CH0 | Buck output voltage | Buck DAC |
| CH1 | LDO output voltage | LDO DAC |
| CH2 | Current sense amplifier output | Shunt + INA185 |
| CH3 | Cell output voltage (Sense line) | Full signal chain |

**Per-cell GPIO expander (TCA6408):**

| GPIO | Function |
|---|---|
| 0 | DMM calibration relay (connects cell output to calibration bus) |
| 1 | (spare) |
| 2 | Buck enable |
| 3 | LDO enable |
| 4 | Load switch (internal discharge) |
| 5 | Output relay control |
| 6 | External load switch |
| 7 | 2-wire/4-wire mode select relay |

### 2.6 Kelvin (4-Wire) Sensing

Each cell output has separate **Force** and **Sense** lines:

- **4-wire mode (default):** Force drives current, Sense feeds back to ADC CH3 for true output voltage at the DUT. Eliminates cable/connector drop errors.
- **2-wire mode:** Force and Sense shorted on-card (via relay on GPIO 7). Simpler wiring when precision isn't critical.
- **Software-controlled** per channel via TCA6408.

```
4-Wire Mode:                          2-Wire Mode:
  Card ──── Force ────→ DUT             Card ──┬── Force ────→ DUT
  Card ←─── Sense ────← DUT                    └── Sense (shorted)
  ADC reads Sense line                  ADC reads Force line
```

### 2.7 Temperature Monitoring

| Location | Sensor | Read by |
|---|---|---|
| Per cell (isolated side) | TMP117 or similar on I2C | STM32H7 via ISO1640 + mux |
| Card-level (MCU side) | STM32H7 internal temp ADC | STM32H7 |
| Base board | TMP117 on CM5 I2C | CM5 |
| Exhaust air | Thermistor on base board | CM5 (fan controller feedback) |

Each cell dissipates up to ~3.3W worst-case (5V/1A output). An 8-channel card at full load ≈ 22W. Temperature sensing is essential for thermal protection and fan speed control.

### 2.8 Isolation Architecture

**Two-tier galvanic isolation:**

The CellSim v2 card uses two independent tiers of galvanic isolation:

**Tier 1 — Card-level isolation (backplane ↔ card MCU domain):**
- Isolated 24V→24V DC-DC converter creates isolated 24V rail for the entire card
- Discrete Ethernet transformer isolates the PHY from backplane differential pairs
- UART digital isolator isolates debug/flash UART from backplane
- Purpose: allows multiple cards to be stacked for high-voltage configurations. Each card's MCU domain floats independently of the backplane ground.

**Tier 2 — Per-cell isolation (card MCU domain ↔ each cell):**
- Per-cell isolated DC-DC (24V→12V) creates individual floating ground domains
- ISO1640 I2C isolator per cell (DACs, GPIO, temp sensor)
- ISO7741 SPI isolator per cell (ADS131M04 ADC)
- Purpose: cells stack in series emulating an 8S battery. Cell 0 GND at ~0V, cell 7 GND at ~40V relative to the card domain. ALL cells must float, including cell 0.

```
Backplane Ground Domain
┌───────────────────────────────────────────────────────────┐
│  24V bus                                                   │
│  Ethernet (differential pairs)                            │
│  UART (TX/RX)                                             │
│  Slot ID, Reset                                           │
└──────────┬──────────┬──────────┬──────────────────────────┘
           │          │          │
    [ISO DC-DC]  [Eth Xfmr]  [UART Iso]  ◄── Tier 1: Card isolation
           │          │          │
┌──────────┴──────────┴──────────┴──────────────────────────┐
│  Card MCU Ground Domain (24V_iso)                          │
│  STM32H723 + LAN8742A + TPSM84209 buck                   │
│    │                                                       │
│    ├── I2C1 → TCA9548A (8 channels)                        │
│    │              │                                        │
│    │     ┌────────┼────────┬────────┬──── ... ──┐          │
│    │     │ Ch0    │ Ch1    │ Ch2         Ch7     │          │
│    │   ISO1640 ISO1640  ISO1640       ISO1640    │ ◄── Tier 2 │
│    │     │        │        │             │       │          │
│    │  Cell 0   Cell 1   Cell 2  ...   Cell 7    │          │
│    │  (GND₀)  (GND₁)  (GND₂)       (GND₇)     │          │
│    │     ↕ ~0V    ↕ ~5V    ↕ ~10V      ↕ ~35V   │  (series stack) │
│    │                                             │          │
│    ├── SPI1 → ISO7741 ×4 → Cells 0–3 ADC        │          │
│    ├── SPI2 → ISO7741 ×4 → Cells 4–7 ADC        │          │
│    │                                             │          │
│    └── Ethernet → LAN8742A → [xfmr] → backplane │          │
└──────────────────────────────────────────────────┘
```

**Voltage ratings:**
- Tier 1 (card isolation): 1.5 kV minimum (DC-DC + Ethernet transformer)
- Tier 2 (per-cell isolation): 1.5 kV minimum (ISO1640 + ISO7741 + per-cell DC-DC)
- Combined: theoretical maximum ~1 kV across a full stack of cards

---

## 3. Controllers

### 3.1 Base Board: Raspberry Pi CM5

The CM5 is the system orchestrator:

| Function | Details |
|---|---|
| REST API server | FastAPI on Python 3.13+, same endpoints as Peak |
| Card discovery | Slot ID bits read over Ethernet at card boot |
| Card firmware updates | Push .bin to cards over Ethernet (custom bootloader) |
| Calibration storage | Per-cell calibration in config dir |
| Web UI | Real-time dashboard, served from CM5 |
| OLED display | System status (hostname, IP, card count, temps) |
| Fan control | PWM output to chassis fans, PID loop on temperature |
| Uplink | GbE to lab network / host PC |

**CM5 connections on base board:**
- GbE to switch IC (RGMII) — uses `atopile/rpi-cm5` package
- USB-C (debug, front panel)
- I2C (OLED display, base board temp sensors, fan controller, 2× TCA6408 calibration mux relay drivers)
- GPIO (E-stop input, system status LEDs, fan PWM)

### 3.2 Cell Card: STM32H723

Uses the `atopile/st-stm32h723` package (proven in Hyperion project).

| Feature | Benefit |
|---|---|
| 480 MHz Cortex-M7 | 100 Hz control loop with DMA I2C — massive headroom |
| Built-in Ethernet MAC | RMII to LAN8742A, same as Hyperion |
| 4× I2C peripherals | 1 bus for cells (TCA9548A 8ch mux), 1 for EEPROM, 2 spare |
| Hardware FPU + DSP | Real-time calibration interpolation |
| USB OTG | DFU firmware update fallback |
| 12-bit internal ADC | Input voltage, board temperature |
| 1 MB Flash | Calibration tables, Ethernet bootloader |

### 3.3 Ethernet PHY (on Cell Card)

Uses `atopile/microchip-lan8742a` package (proven in Hyperion project).

- RMII interface to STM32H723
- 100 Mbps — plenty for 8ch × 100 Hz
- Connects via backplane to GbE switch (auto-negotiates to 100M)

### 3.4 Card Identity (EEPROM + MAC Address)

Each card carries a **Microchip 24AA025E48** I2C EEPROM with a factory-programmed globally unique EUI-48 identifier. This solves two problems with one IC:

| Function | Details |
|---|---|
| **Unique card ID** | 48-bit EUI-48 (globally unique, factory-programmed, read-only) |
| **Ethernet MAC address** | Same EUI-48 used as LAN8742A MAC — no manual MAC assignment needed |
| **User EEPROM** | 256 bytes writable — card metadata (manufacturing date, HW revision, card type) |
| **Calibration binding** | CM5 stores calibration data keyed by this ID — survives card moves between slots |

**Why not use the STM32H723 built-in 96-bit UID?**
The STM32's UID is tied to the MCU die. If the MCU is replaced during rework, all calibration data for that card is orphaned. The EEPROM stays with the PCB.

**I2C connection:** On the card's non-isolated I2C3 bus (spare), address 0x50 (fixed). Read at boot by card firmware, reported to CM5 in mDNS TXT record and card status API.

**Card boot sequence with identity:**
1. STM32H723 reads 24AA025E48 EUI-48 from I2C3
2. Programs LAN8742A MAC address register with EUI-48
3. Reads slot ID from backplane GPIO pins
4. Assigns IP: `10.0.0.{100 + slot_id}`
5. Advertises mDNS: `cellsim-card-{slot_id}.local` with TXT records: `id={EUI-48}, type=cell, fw={version}`
6. CM5 discovers card, matches EUI-48 to stored calibration data

**Package:** `atopile/microchip-24aa025e48` (to create — SOT-23-5 or MSOP-8, ~$0.50)

### 3.5 STM32H723 Pin Budget (LQFP-100)

| Function | Pins | Notes |
|---|---|---|
| Ethernet RMII | 9 | REF_CLK, MDIO, MDC, CRS_DV, RXD0/1, TX_EN, TXD0/1 |
| I2C1 (all 8 cells) | 2 | SCL, SDA → TCA9548A (8ch mux, DACs + GPIO + temp) |
| I2C3 (card identity) | 2 | 24AA025E48 EEPROM (0x50), card-level temp sensor |
| SPI1 (cells 0-3 ADC) | 3 | SCLK, MOSI, MISO → 4× ISO7741 (ADS131M04) |
| SPI1 CS lines | 4 | CS0..CS3 → each ISO7741 forward ch C |
| SPI1 MISO mux select | 2 | CD74HC4052 address bits (select return ch) |
| SPI2 (cells 4-7 ADC) | 3 | SCLK, MOSI, MISO → 4× ISO7741 (ADS131M04) |
| SPI2 CS lines | 4 | CS4..CS7 → each ISO7741 forward ch C |
| SPI2 MISO mux select | 2 | CD74HC4052 address bits (select return ch) |
| USB OTG FS | 2 | DFU fallback |
| UART (debug/flash) | 2 | TX, RX (isolated via UART isolator to backplane) |
| SWD | 2 | SWDIO, SWCLK |
| Internal ADC inputs | 2 | Input voltage divider, temp |
| HSE crystal | 2 | 25 MHz (shared with PHY) |
| Slot ID inputs | 4 | Active-low from backplane (2⁴ = 16 slots) |
| Boot/Reset | 3 | BOOT0, NRST, user button |
| GPIO (spare) | ~6 | Status LED, etc. (2 freed from I2C2 removal) |
| **Total** | **~51** | Well within 100-pin budget |

---

## 4. Power Architecture

The power architecture is specified bottom-up: cell output requirements drive per-cell component selection, which cascades to per-card power draw, which sizes the system PSU.

### 4.1 Cell Output Requirements (Design Target)

| Parameter | v1 (proven) | v2 (target) | Notes |
|---|---|---|---|
| Output voltage | 0–4.5 V | **0–5 V** | +11%, TPS563201 buck max ~5.5V |
| Output current | 500 mA | **1 A** | +100%, drives thermal + component changes |
| Output power (max) | 2.25 W | **5 W** | Per-cell delivered to DUT |
| Voltage resolution | ~1 mV | < 1 mV | 12-bit DAC over range |
| Voltage accuracy | ±10 mV | **±5 mV** | After calibration |

### 4.2 Per-Cell Power Path (Isolated Domain)

Same proven topology as v1/Peak — isolated supply → digital buck → digital LDO — but uprated for 5 V / 1 A. Each cell is powered from the card's isolated 24V rail (24V_iso, output of card-level isolated DC-DC):

```
24V_iso (from card-level isolated DC-DC)
  │
  ├── Per-cell Isolated DC-DC (24V → 12V, 3W) ── [CELL DOMAIN, floating]
  │   YLPTEC B2412S-3WR2 (C5369517, $1.95)             │
  │                                                      │
  │         ┌──── I2C Isolator (ISO1640) ────────────────┤ (DACs + GPIO + temp)
  │         ├──── SPI Isolator (ISO7741) ───────────────┤ (ADS131M04 ADC)
  │         │                                            │
  │    (Card MCU domain)                          (Cell domain)
  │                                                      │
  │                                               ┌──────┴──────┐
  │                                               │  3.3V LDO   │ 12V → 3.3V (control rail)
  │                                               │  (LDK220)   │ powers: DACs, ADC, GPIO exp.
  │                                               └──────┬──────┘
  │                                                      │
  │                                               Digital Buck (TPS563201DDCR)
  │                                               MCP4725 DAC → feedback network
  │                                               12V → ~5.5V (variable, tracks LDO + margin)
  │                                               External inductor, 3A, 500 kHz
  │                                                      │
  │                                               Digital LDO (TLV75901)
  │                                               MCP4725 DAC → feedback network
  │                                               Buck out → 0–5V output (fine regulation)
  │                                               Output cap: 10µF ceramic (0805)
  │                                                      │
  │                                              Current Sensor
  │                                               INA185A2 (50× gain) + 50mΩ shunt
  │                                                      │
  │                                               Output Relay (DPDT, HFD4/5)
  │                                                   │      │
  │                                                FORCE    SENSE
  │                                              (Kelvin output connector)
```

#### 4.2.1 Stage 1: Per-Cell Isolated DC-DC Converter

Provides galvanic isolation per cell (cells stack in series at different potentials up to ~40 V total for 8S). Each cell's isolated DC-DC is powered from the card's isolated 24V rail (24V_iso), creating a second tier of isolation.

| Parameter | v1 (B1205S-2WR2) | v2 (YLPTEC B2412S-3WR2) | Notes |
|---|---|---|---|
| Input voltage | 10.8–13.2 V | **21.6–26.4 V (24V nom.)** | Matches 24V_iso rail |
| Output voltage | 5 V ±10% | **12 V ±10% (11.4–12.6V)** | Headroom for buck + control LDO |
| Output current | 400 mA (2 W) | **250 mA (3 W)** | Sufficient — see power budget below |
| Isolation | 1.5 kV | 1.5 kV | OK |
| Efficiency | ~80% | ~80% | — |
| LCSC | C2992386 | **C5369517** | $1.95 (325 stock) |
| Package | SIP-6 THT | **SIP-4 THT** | PWRM-TH_BXXXXS-3WR2 |
| Atopile package | `atopile/ylptech-byyxx` | `atopile/ylptech-byyxx` | YLPTEC_B2412S_3WR2 module |

**Why 12 V output (not 8 V or 5 V):**
- LDO needs 5 V + 0.225 V dropout = 5.225 V minimum input
- Buck (TPS563201) needs Vin > Vout + dropout: 12V >> 5.5V, comfortable margin
- 12 V provides the 3.3V per-cell control rail with comfortable headroom (via LDK220)
- 12 V is a standard voltage with readily available isolated DC-DC modules
- The slightly higher voltage vs 8V means lower current for the same power, reducing losses

**Why 3 W is sufficient:**
- Buck at worst case (5V/1A output, 90% eff.): 5.5W input from 12V = 0.46A
- Control rail: ~55 mW (negligible)
- Total per-cell load from 12V rail: ~0.52A × 12V = **~6.2W**
- At 80% efficiency from 24V: 6.2W / 0.80 = **7.7W from 24V_iso** → 0.32A from 24V
- **BUT** the B2412S-3WR2 is only rated 3W (250mA @ 12V). This limits maximum continuous cell output to approximately:
  - 3W at 12V = 250mA → buck input power limited to 3W
  - At 90% buck efficiency: ~2.7W available at buck output
  - At 5V output: 2.7W / 5V = **~540 mA continuous**
  - **For full 1A operation**, need a higher-power variant or parallel units. See open items.

**Decoupling:**
- Input: 2.2 µF ceramic (0805) — per YLPTEC datasheet
- Output: 10 µF ceramic (0805)

**Power dissipation at 3W max output:** (3W / 0.80) - 3W = **0.75W waste heat per cell** — manageable.

**STATUS: RESOLVED (component selected). OPEN: 3W may limit max cell current to ~540mA — evaluate if 1A continuous is truly required or if typical 300mA operation is sufficient. For 1A, consider YLPTEC B2405S-2WR3 (2W, 24V→5V) + higher-power buck, or find a 24V→12V 5W+ part.**

#### 4.2.2 Stage 2: Digital Buck Converter

Coarse voltage regulation. DAC-controlled via MCP4725 modulating the TPS563201 feedback network. Same proven part from v1, now operating from a 12V input rail (from per-cell isolated DC-DC).

| Parameter | v1 value | v2 value | Status |
|---|---|---|---|
| IC | TPS563201DDCR | **TPS563201DDCR** | **Reuse** |
| Input voltage | 4.5–17 V (from 5V iso) | 4.5–17 V (from 12V iso) | OK (12V within range) |
| Output voltage | 0.768–7 V | **0.768–5.5 V** | Max cell output ~5V |
| Output current | 3 A rated | 3 A rated | OK (1A load = 33% utilization) |
| Vref | 0.768 V | 0.768 V | — |
| Efficiency | ~90% | ~90% | Same part |
| Switching freq | 500 kHz | 500 kHz | — |
| LCSC | C116592 | C116592 | ~$0.35 |
| Package | SOT-23-6 | SOT-23-6 | External inductor required |

**Feedback network (from v1 codebase, proven):**
- R_top: 37 kΩ ±2%, R_bottom: 10 kΩ ±2%, Ctrl_resistor: 24 kΩ ±2%
- DAC A0 tied to VIN → address 0x61
- Vout = Vref × (1 + R_top/R_bottom) adjusted by DAC current injection
- Configured for 0–5 V output range (proven in v1)

**Supporting components:**
- Input caps: 10 µF + 10 µF (0805) + 100 nF (0402)
- Output caps: 2× 22 µF (0805)
- Bootstrap cap: 100 nF (0402)
- External inductor: 4.7 µH (e.g. Wurth WE-LQS 4040, 3A rated)
- Enable: 10 kΩ pull-up (0402), controlled via TCA6408 GPIO P2

**Buck operating point at worst case (5V/1A cell output):**
- Input: 12 V, Output: 5.5 V, Load: 1 A
- Pin = 5.5 V × 1 A / 0.90 = 6.1 W
- **Loss: 0.6 W** (at 90% efficiency)
- Vin/Vout ratio = 2.18 → good operating point

**Note on TPSM863257 upgrade path:** The TPSM863257RDXR (integrated inductor, 1.2 MHz, 3–17V input) was considered as an upgrade but is deferred to Phase 2. The TPS563201 is proven in v1 and the 12V input rail is well within its 4.5–17V range. The main advantage of TPSM863257 (integrated inductor) saves one component but adds $0.50/cell and requires feedback network recalculation for the 0.6V Vref.

**STATUS: RESOLVED. Reusing v1 part (TPS563201) with proven feedback network. 12V input is comfortable within 4.5–17V range.**

#### 4.2.3 Stage 3: Digital LDO (Fine Regulation)

Provides low-noise, precise output regulation. DAC-controlled via MCP4725 modulating the TLV75901 feedback network.

| Parameter | v1 value | v2 value | Status |
|---|---|---|---|
| IC | TLV75901PDRVR | TLV75901PDRVR | **Reuse — now works** |
| Input voltage | 1.5–6 V | 1.5–6 V | OK (buck max output 5.5V < 6V) |
| Output voltage | 0.55–5.5 V | 0.55–**5 V** | OK (5V within 5.5V LDO max) |
| Output current | 1 A rated | 1 A (continuous) | 0% margin but proven in v1 |
| Vref | 0.55 V | 0.55 V | — |
| Dropout voltage | 225 mV | 225 mV (typ @ 25°C) | Rises with temp |
| LCSC | C544759 | C544759 | — |
| Package | WSON-6 (2×2 mm) | WSON-6 | Adequate with buck tracking |

**v1 feedback network (from codebase):**
- R_top: 60 kΩ ±2%, R_bottom: 10 kΩ ±2%, Ctrl_resistor: 43 kΩ ±2%
- DAC A0 tied to GND → address 0x60
- v1 configured for 0–5 V output range
- Output cap: increase from 1 µF (0402) to **10 µF ceramic (0805)** for 1A transient response

**v2 status — RESOLVED (P1 blocker cleared):**

With the TPS563201 buck capping at 5.5V output, the TLV75901 (max Vin = 6V) now operates within its rated input range. The LDO can output 0–5V with comfortable margin:

1. **Input voltage:** Buck max output = 5.5V, well within TLV75901 max Vin of 6V. ✓
2. **Output voltage:** 0–5V is within the TLV75901's 0.55–5.5V adjustable range. ✓
3. **Thermal dissipation at 1A:** With buck tracking, max LDO dropout ≈ 0.5V → P = 0.5W. WSON-6 Θ_JA ≈ 60°C/W → 30°C rise. Acceptable. ✓
4. **Output capacitance:** 10 µF ceramic (0805). The LDO's PSRR (>60 dB at 500 kHz buck switching frequency) handles ripple rejection without an LC filter. ✓

**Buck-tracks-LDO control strategy (essential for v2):**
The firmware must set the buck output to Vout_target + ~0.5V headroom. This keeps LDO dropout loss manageable across the full range:

| Cell output | Buck setpoint | LDO dropout | LDO loss @ 1A |
|---|---|---|---|
| 5.0 V | 5.5 V | 0.5 V | 0.5 W |
| 4.0 V | 4.5 V | 0.5 V | 0.5 W |
| 2.0 V | 2.5 V | 0.5 V | 0.5 W |
| 0.5 V | 1.5 V | 1.0 V | 1.0 W |

This approach caps LDO dissipation at ~1W across the range.

**STATUS: RESOLVED. TLV75901 works as-is with TPS563201 buck (max 5.5V input to LDO). Feedback network unchanged from v1 (already supports 0–5V). Only output cap upgrade needed (1µF → 10µF).**

#### 4.2.4 Stage 4: Current Sensor

| Parameter | v1 value | v2 value | Status |
|---|---|---|---|
| IC | INA185A2IDRLR (50× gain) | Same | OK |
| Shunt | 100 mΩ ±10% (0805) | **50 mΩ ±1% (0805)** | Change for 1A range |
| Max current | 500 mA | **1 A** | — |
| LCSC | C2059320 | C2059320 | — |

**v1 (from codebase):** `current_sense.current = 0.5A`, `shunt.value = 100mohm +/- 10%`
- At 0.5A: V_shunt = 50 mV, V_out = 50 mV × 50 = 2.5 V — good ADC utilization

**v2 recalculation with 50 mΩ shunt:**
- At 1A: V_shunt = 50 mV, V_out = 50 mV × 50 = 2.5 V — same ADC utilization
- Shunt power: 1A² × 0.05Ω = **50 mW** (well within 0805 rating)
- INA output at 1A: 0.05 × 1 × 50 = 2.5V; through 2:5 divider → 1.0V at ADC (within 1.2V full-scale, see §4.2.8)

**STATUS: OK. Update shunt value from 100 mΩ to 50 mΩ, tighten tolerance to ±1%.**

#### 4.2.5 Stage 5: Output Relay

| Parameter | v1 value | v2 value | Status |
|---|---|---|---|
| Relay | HFD4/5-SR (DPDT) | Same | OK |
| Contact rating | ≥1A | ≥1A | OK for v2 |
| Coil voltage | 5V ±10% | 5V ±10% | Powered from 5V card rail (non-isolated) for v1; from isolated 8V→5V for v2 |
| Driver | IRLML0040 N-FET | Same | OK |
| Control | TCA6408 GPIO P5 | Same | — |

**v2 note:** Relay coil power comes from the cell's isolated domain. With 12V isolated output, add a 5V regulator per cell or use the 12V rail with appropriate relay selection. Alternatively, the relay coil can be powered from the 3.3V control rail via a higher-resistance coil variant (3V coil relay).

**STATUS: OK. Verify relay coil supply in isolated domain.**

#### 4.2.6 Output Path Resistance Budget

Maximum allowed resistance from LDO output to cell output connector, ensuring acceptable voltage drop at 1A:

| Element | Resistance | Voltage Drop @1A |
|---|---|---|
| Current sense shunt | 50 mΩ | 50 mV |
| PCB trace (LDO→shunt→relay) | ≤20 mΩ | 20 mV |
| Output relay contacts | ~100 mΩ | 100 mV |
| PCB trace (relay→connector) | ≤10 mΩ | 10 mV |
| Connector contact resistance | ~20 mΩ | 20 mV |
| **Total** | **≤200 mΩ** | **≤200 mV** |

**Design notes:**
- 200 mV drop at 1A is within the LDO's regulation capability. Kelvin sense feeds back the actual output voltage to ADS131M04 CH3, so the firmware compensates for the drop.
- PCB layout: use ≥1 oz copper, ≥0.5 mm trace width for the force path (target ≤10 mΩ/cm).
- The shunt resistor drop is intentional (current measurement), not waste.
- The 200 mV total drop is well within the 500 mV buck-LDO tracking margin — the buck can always provide enough headroom for the LDO to regulate at the target output voltage.

**STATUS: Spec. Verify during PCB layout (trace resistance) and prototype validation.**

#### 4.2.7 Per-Cell Internal Control Rail

Each cell's isolated domain also requires a 3.3V rail for the I2C/SPI devices (DACs, ADC, GPIO expander, isolator secondary sides).

| Parameter | v1 value | v2 value | Status |
|---|---|---|---|
| IC | LDK220M-R | **LDK220M-R** | **Reuse** (Vin max 13.2V, 12V input OK) |
| Input | 5V (from B1205S) | **12V** (from YLPTEC B2412S-3WR2) | 12V within LDK220 Vin range |
| Output | 3.3V ±5% | 3.3V ±5% | — |
| Current | 200 mA max | ≥50 mA | Sufficient for I2C/SPI devices |
| Dropout | ~225 mV | ~225 mV | 12V→3.3V = 8.7V headroom, no concern |

**Loads on 3.3V control rail:**
- ISO1640 isolated side: ~3 mA
- ISO7741 isolated side: ~3 mA (SPI isolator for ADC)
- ADS131M04 ADC: ~1 mA (3.3 mW @ 3.3V)
- 2× MCP4725 DAC: ~0.4 mA each
- TCA6408 GPIO: ~0.1 mA
- TMP117 temp sensor: ~0.1 mA
- I2C pull-ups (2× 2 kΩ): ~3.3 mA
- **Total: ~11.8 mA** — well within LDK220's 200 mA budget

**Control LDO dissipation at 12V input:** (12V - 3.3V) × 11.8 mA = **103 mW** — acceptable, slightly higher than v1 due to 12V input vs 5V. Well within SOT-23-5 thermal limits.

**STATUS: RESOLVED. LDK220M-R reused — Vin max of 13.2V accommodates the 12V ±10% input from the isolated DC-DC (11.4–12.6V). The `st-ldk220-local/` package is already integrated in cell-card.**

#### 4.2.8 ADC Input Conditioning

Each ADS131M04 channel requires analog input conditioning to map the cell-domain signals into the ADC's ±1.2V input range (internal reference, PGA gain = 1). All four channels use resistive voltage dividers followed by a first-order RC anti-aliasing filter.

**ADS131M04 key constraints:**
- Internal reference: 1.2V (typical 1.25V) — no external VREF input
- Single-ended usable range: 0 to +1.2V (gain = 1)
- Input impedance: ~330 kΩ at gain 1–4
- All 4 channels on isolated 3.3V domain (AVDD = 3.3V)

**Per-channel input conditioning:**

| CH | Signal | Source Range | Divider | ADC Input Range | Headroom | Anti-Alias f_c | Notes |
|----|---|---|---|---|---|---|---|
| 0 | Buck output voltage | 0–5.5V | 1:5 | 0–1.10V | 8% | ~50 kHz | 500 kHz buck ripple — tighter filter |
| 1 | LDO output voltage | 0–5.0V | 1:5 | 0–1.00V | 17% | ~100 kHz | Clean LDO output |
| 2 | Current sense (INA185 out) | 0–2.5V | 2:5 | 0–1.00V | 17% | ~100 kHz | INA185A2: 50× gain, 50 mΩ shunt; INA BW ~350 kHz pre-filters |
| 3 | Kelvin sense voltage | 0–5.0V | 1:5 | 0–1.00V | 17% | ~100 kHz | 4-wire sense line, high-Z input |

**Anti-aliasing filter:**
- **Topology:** Series R_filter + shunt C_filter to AGND, between divider output and ADC input pin
- **CH0 cutoff ~50 kHz:** Buck switching at 500 kHz → ~20 dB rejection at switching frequency
- **CH1/2/3 cutoff ~100 kHz:** Clean signals, 10× above control bandwidth (10 kHz)
- **Capacitor dielectric:** C0G/NP0 mandatory (no voltage-dependent capacitance)
- **Source impedance target:** 2–5 kΩ total (divider Thévenin ∥ R_filter) — low enough for ADC settling, high enough for ESD protection
- Delta-sigma oversampling + digital decimation filter provides additional noise rejection

**Resolution analysis (at ~19 ENOB, 10 kHz output rate):**

| CH | Signal Range | Divider | Resolution (at signal) | Notes |
|----|---|---|---|---|
| 0 | 0–5.5V | 1:5 | ~10.5 µV | Well under ±1 mV target |
| 1 | 0–5.0V | 1:5 | ~9.5 µV | Well under ±1 mV target |
| 2 | 0–2.5V | 2:5 | ~4.8 µV → ~1.9 µA | Well under ±0.1 mA target |
| 3 | 0–5.0V | 1:5 | ~9.5 µV | Well under ±1 mV target |

**AGND routing:**
- Isolated analog ground plane under ADC + all input conditioning components
- Single-point connection to isolated digital ground near ADC AGND pin
- No digital traces routed under analog area

### 4.3 Per-Cell Power Budget Summary

**Note:** Per-cell isolated DC-DC (B2412S-3WR2) is rated 3W (250mA @ 12V). This limits continuous operation — see §4.2.1 for details. The budget below shows the realistic operating envelope.

**Maximum continuous (limited by 3W iso DC-DC): ~5V output, ~540mA load**

| Stage | Input | Output | Loss | Efficiency |
|---|---|---|---|---|
| Isolated DC-DC (80% eff.) | 24V_iso × 0.16A = **3.75W** | 12V × 0.25A = 3.0W | **0.75W** | 80% |
| Digital Buck (90% eff.) | 12V × 0.25A = 3.0W | 5.5V × 0.49A = 2.7W | **0.3W** | 90% |
| Digital LDO (tracking buck) | 5.5V × 0.49A = 2.7W | 5.0V × 0.49A = 2.45W | **0.25W** | 91% |
| Current Sensor (50mΩ) | 2.45W | 2.45W | **0.012W** | 99.5% |
| Output Relay | 2.45W | 2.45W | **~0.02W** | ~100% |
| 3.3V control rail (LDK220) | 0.14W | 0.039W | **0.103W** | — |
| Relay coil | — | — | **~0.1W** | — |
| **TOTAL per cell** | **3.75W from 24V_iso** | **2.45W to DUT** | **1.5W waste** | **65% end-to-end** |

**Per-cell 24V_iso current:** 3.75W ÷ 24V = **0.16A per cell** (at max continuous)

**Typical operating point (3.7V / 300mA = 1.1W):**

| Stage | Input | Output | Loss | Efficiency |
|---|---|---|---|---|
| Isolated DC-DC (80% eff.) | 24V_iso × 0.08A = **1.88W** | 12V × 0.13A = 1.5W | **0.38W** | 80% |
| Digital Buck (90% eff.) | 12V × 0.13A = 1.5W | 4.2V × 0.3A = 1.26W | **0.14W** | 90% |
| Digital LDO (tracking) | 4.2V × 0.3A = 1.26W | 3.7V × 0.3A = 1.1W | **0.15W** | 88% |
| Other | — | — | **~0.25W** | — |
| **TOTAL per cell** | **1.88W from 24V_iso** | **1.1W to DUT** | **0.92W waste** | **59% e2e** |

### 4.4 Per-Card Power Budget

Each card has 8 cells plus card-level electronics. The card receives 24V from the backplane, passes it through a card-level isolated DC-DC (24V→24V), then distributes 24V_iso to both the card MCU domain (via TPSM84209 buck) and the 8 per-cell isolated DC-DCs.

#### 4.4.1 Card Electronics Rail

```
24V (from backplane)
  │
  └──→ Isolated DC-DC (24V → 24V, 20W) ──→ 24V_iso
            e.g. TDPOWER TDK20-24S24WH              │
            (card-level galvanic isolation)           │
                                                      ├──→ TPSM84209 Buck (24V → 3.3V, 2.5A)
                                                      │         └── STM32H723, LAN8742A, mux,
                                                      │             TCA9548A, ISO1640/ISO7741 non-iso ×8
                                                      │
                                                      └──→ 8× Per-cell isolated DC-DC (24V → 12V, 3W)
                                                                └── Per-cell power chain (see §4.3)
```

| Component | Supply | Current Draw | Notes |
|---|---|---|---|
| STM32H723 (active, I2C + SPI DMA + Ethernet) | 3.3V | ~150 mA | Worst-case with all peripherals |
| LAN8742A PHY | 3.3V | ~80 mA | Active link |
| 1× TCA9548A I2C mux | 3.3V | ~1 mA | Single mux, 8 channels |
| 8× ISO1640 non-isolated side | 3.3V | ~24 mA | 3 mA each |
| 8× ISO7741 non-isolated side | 3.3V | ~24 mA | 3 mA each (SPI isolator) |
| 2× CD74HC4052 MISO mux | 3.3V | ~1 mA | SPI MISO multiplexers |
| Misc (pull-ups, indicators) | 3.3V | ~10 mA | — |
| **3.3V total** | 3.3V | **~290 mA** | Via TPSM84209 direct to 3.3V |

**Card-level buck (TPSM84209RKHR):**
- Input: 24V_iso, Output: 3.3V @ 0.29A (direct, no intermediate 5V stage needed)
- Power: 3.3V × 0.29A = 0.96W output, ~1.07W input (at 90% eff.)
- Integrated inductor, 4.5–28V in, 1.2–6V out, 2.5A rated
- **Card electronics loss: ~0.11W** (better efficiency than 24V→5V→3.3V two-stage)

**Card-level isolated DC-DC (24V→24V):**
- e.g. TDPOWER TDK20-24S24WH (20W, proven in Peak 48ch)
- Input: 24V (backplane), Output: 24V_iso
- At 90% efficiency: 20W output capacity, 22.2W input
- Powers: TPSM84209 (1.07W) + 8× per-cell DC-DCs (8 × 3.75W = 30W max)
- **Note:** 20W TDK20 limits total card power. At typical loads (~15W total) this is adequate. For full 8× max continuous, may need higher-power variant.

**Note:** Per-cell SK6805 LEDs removed. Card status can be reported via Ethernet to CM5 OLED/dashboard.

#### 4.4.2 Card Total

**Max continuous (limited by 3W per-cell iso DC-DC: 8 cells at ~5V/540mA)**

| Load | 24V Current | Power | Waste Heat |
|---|---|---|---|
| 8× cell isolated supplies | 8 × 0.16A = **1.25A** | 30W | **6.0W** |
| Card-level iso DC-DC (90% eff.) | — | — | **3.3W** |
| Card electronics (TPSM84209) | 0.04A | 1.07W | 0.11W |
| **Card total (max continuous)** | **~1.4A** | **~34W** | **~9.4W** |

**Typical (8 cells at 3.7V/300mA)**

| Load | 24V Current | Power | Waste Heat |
|---|---|---|---|
| 8× cell (3.7V/300mA) | 8 × 0.08A = **0.63A** | 15W | **3.0W** |
| Card-level iso DC-DC (90% eff.) | — | — | **1.7W** |
| Card electronics | 0.04A | 1.07W | 0.11W |
| **Card total (typical)** | **~0.7A** | **~18W** | **~4.8W** |

**Backplane current per slot:** ~1.4A max continuous → **4× power pins at 1.5A each** provides ample margin.

### 4.5 System Power Budget

#### 4.5.1 Full System Power Tree

```
AC Mains (110/240V)
  │
  ├── IEC C14 inlet + fuse + EMI filter
  │
  ├── Meanwell PSU (24V DC output)
  │     │
  │     ├── 24V Bus (on backplane, heavy copper)
  │     │     │
  │     │     ├── INA228 shunt (total system current sense)
  │     │     │     │
  │     │     │     ├── Slot 0: G5Q relay (NO) → INA3221 shunt → Card connector (~1.4A max)
  │     │     │     │         Card: 24V → [ISO DC-DC 24V→24V] → 24V_iso → TPSM84209 + 8× cells
  │     │     │     ├── Slot 1: G5Q relay (NO) → INA3221 shunt → Card connector (~1.4A max)
  │     │     │     ├── ...
  │     │     │     └── Slot 15: G5Q relay (NO) → INA3221 shunt → Card connector (~1.4A max)
  │     │     │
  │     │     └── Relay coil supply bus (24V_COIL)
  │     │           │
  │     │           ├── E-Stop button (NC, series) ← kills all relay coils
  │     │           │
  │     │           ├── MCP23017 #1 → N-FET × 8 → Relay coils 0-7
  │     │           └── MCP23017 #2 → N-FET × 8 → Relay coils 8-15
  │     │
  │     └── Base Board 24V (always-on, not behind relays)
  │           │
  │           ├── Buck (24V → 5V) → CM5 (5V, ~2A)
  │           ├── Buck (24V → 5V) → GbE Switch ICs (×5 RTL8305NB)
  │           ├── LDO (5V → 3.3V) → OLED, temp sensors, misc I2C
  │           └── Fan drivers (24V PWM, 2–4× 120mm fans)
  │
  └── Fan power: 24V, ~0.5A per 120mm fan × 4 = 2A
```

#### 4.5.2 System Power Summary

| Configuration | Cards | 24V Current | PSU Input Power | Waste Heat |
|---|---|---|---|---|
| **Min (1 card, typical load)** | 1 | 0.7A + 1.5A base = 2.2A | 53W | 5W |
| **Small (4 cards, typical)** | 4 | 2.8A + 1.5A base = 4.3A | 103W | 19W |
| **Medium (10 cards, typical)** | 10 | 7.0A + 1.5A base = 8.5A | 204W | 48W |
| **Full (16 cards, typical)** | 16 | 11.2A + 1.5A base = 12.7A | 305W | 77W |
| **Full (16 cards, MAX CONTINUOUS)** | 16 | 22.4A + 1.5A base = 23.9A | 574W | 150W |

**Note:** Max continuous is limited by the 3W per-cell isolated DC-DC (~540mA per cell, not 1A). System power is significantly reduced vs previous estimates due to lower per-cell power draw.

**Base board load estimate:**
- CM5: ~5W (5V @ 1A)
- 5× RTL8305NB switch ICs: ~5W
- Fans (4×): ~24W (24V × 0.25A each)
- OLED, sensors, LEDs: ~1W
- **Base board total: ~35W → ~1.5A from 24V** (including regulation losses)

#### 4.5.3 PSU Selection

| Scenario | Min PSU Rating | Recommendation |
|---|---|---|
| ≤4 cards (32 cells), typical | 103W | **Meanwell LRS-150-24** (150W, 6.5A) |
| ≤10 cards (80 cells), typical | 204W | **Meanwell LRS-350-24** (350W, 14.6A) |
| 16 cards, typical | 305W | **Meanwell LRS-350-24** (350W, 14.6A) |
| 16 cards, max continuous | 574W | **Meanwell LRS-600-24** (600W, 25A) |

**Reality check:** The 3W per-cell isolated DC-DC significantly reduces system power. Even 16 cards at max continuous only draws ~574W, easily handled by a single LRS-600-24. System power requirements are roughly halved compared to the original 8W/cell estimate.

**For initial Phase 1–3 development (≤4 cards):** LRS-150-24 is sufficient.

### 4.5a Per-Slot Power Switching & Monitoring

Each card slot has individual power isolation via a relay, with per-slot current monitoring and a hardware E-stop that kills all slots simultaneously.

#### 4.5a.1 Per-Slot Relay

Each of the 16 slots has a dedicated **Omron G5Q-1A4 DC24** relay (SPST-NO, 10A @ 30VDC, LCSC C89311, $0.52):

| Parameter | Value |
|---|---|
| Contact form | SPST-NO (1 Form A) |
| DC switching rating | 10A @ 30VDC (300W max) |
| Per-slot load | 3.45A @ 24V worst case (83W) — 3× margin |
| Coil voltage | 24VDC |
| Coil power | 200mW (coil resistance 2.88 kΩ) |
| Coil current | 8.3 mA per relay |
| Contact material | Cadmium-free Ag alloy |
| Mechanical life | 10M cycles |
| Electrical life | 100K cycles (at rated load) |
| Footprint | 20 × 10 mm (4-pin THT) |

**Why relay instead of solid-state (BTS5215L, P-FET, etc.):**
- Relay provides galvanic isolation when open — true card disconnect
- E-stop works by simply cutting relay coil supply — no firmware involved, purely hardware safety
- Zero on-resistance concerns (relay contacts < 100 mΩ vs. FET RDS(on))
- Dual-purpose: replaces both the E-stop bus relay and per-slot FET switch

#### 4.5a.2 Relay Drive Circuit

```
24V_BUS ─────────────────────────────────────────→ Relay Common (pin 1)
                                                     Relay NO (pin 2) ─→ INA3221 shunt ─→ Slot connector

24V_COIL ──[E-Stop NC]──┬──────────────────────────→ Relay coil + (pin 3)
                         │
                         │   Relay coil - (pin 4) ──→ N-FET drain
                         │                            N-FET source → GND
                         │                            N-FET gate ← MCP23017 GPIO (via 1k resistor)
                         │                            Flyback diode (1N4148) across coil
                         │
                         └── (repeated ×16)
```

**Drive components per slot:**
- 1× N-FET (IRLML0040 or similar, SOT-23, 200mW drive) — gate driven by MCP23017 GPIO
- 1× Flyback diode (1N4148W, SOD-323) — protects N-FET from coil back-EMF
- 1× 1kΩ gate resistor (0402)

**GPIO expanders:**
- 2× MCP23017 (16-bit I2C GPIO) on CM5 I2C bus — 8 relay drives each
- MCP23017 #1 (addr 0x20): slots 0–7
- MCP23017 #2 (addr 0x21): slots 8–15
- Default power-on state: all outputs LOW → all relays open → all cards de-powered
- Firmware sequence: discover card → close relay → wait for card boot → establish TCP

**E-stop:**
- NC mushroom-head button in series with 24V_COIL supply
- Pressing E-stop breaks coil supply to all 16 relays → all relays open → all cards instantly lose 24V
- Does NOT affect base board power (CM5, switches, fans stay running)
- Total coil current: 16 × 8.3 mA = 133 mA (well within E-stop contact rating)

#### 4.5a.3 Per-Slot Current Monitoring

**INA3221** (3-channel current/power monitor, I2C) — 6× INA3221 monitors 16 slots (3 channels × 6 = 18 channels, 16 used):

| Parameter | Value |
|---|---|
| Shunt resistor | 10 mΩ (per slot, 0.1W at 3.45A, 1206 package) |
| Full-scale current | 8.19A (±81.92 mV range, 10 mΩ shunt) |
| Resolution | ~0.5 mA (13-bit ADC, 40 µV LSB) |
| Position | Between relay NO contact and slot connector (downstream) |
| Bus voltage measurement | Yes — monitors 24V at each slot |

**INA3221 I2C addressing (6 devices):**
- Behind TCA9548A mux on CM5 I2C bus (same mux used for other backplane I2C devices)
- All INA3221 at address 0x40 (A0=GND), selected by mux channel

**INA228** (main bus monitor):
- Single device on 24V bus input (before relay distribution)
- Monitors total system current + power
- I2C address 0x45 on CM5 I2C bus

#### 4.5a.4 Backplane I2C Bus (CM5)

All backplane I2C devices share a single I2C bus on the CM5:

| Device | Qty | Address | Muxed? | Function |
|---|-----|---|---|---|
| TCA9548A | 1 | 0x70 | — | I2C mux for INA3221 + other backplane devices |
| MCP23017 #1 | 1 | 0x20 | No | Relay drive GPIO (slots 0–7) |
| MCP23017 #2 | 1 | 0x21 | No | Relay drive GPIO (slots 8–15) |
| INA228 | 1 | 0x45 | No | Main bus current monitor |
| INA3221 ×6 | 6 | 0x40 | Yes (mux ch 0–5) | Per-slot current monitoring |
| TCA6408 #1 | 1 | 0x20 | Yes (mux ch 6) | Calibration relay drive (slots 0–7) |
| TCA6408 #2 | 1 | 0x21 | Yes (mux ch 7) | Calibration relay drive (slots 8–15) |
| EMC2101 | 1 | 0x4C | No | Fan controller + base temp |
| TMP117 | 1 | 0x48 | No | Base board temp sensor |

### 4.6 Thermal Budget & Cooling

#### 4.6.1 Heat Sources by Level

| Level | Source | Max Continuous | Typical |
|---|---|---|---|
| Per cell | Isolated DC-DC (B2412S-3WR2) | 0.75W | 0.38W |
| Per cell | Buck regulator (TPS563201) | 0.3W | 0.14W |
| Per cell | LDO regulator (TLV75901) | 0.25W | 0.15W |
| Per cell | Other (relay, shunt, ctrl rail) | 0.22W | 0.15W |
| **Per cell total** | | **1.5W** | **0.92W** |
| Per card | Card-level iso DC-DC (24V→24V) | 3.3W | 1.7W |
| **Per card (8 cells + card electronics)** | | **~15.4W** | **~9.6W** |
| Base board | CM5 + switches + fans | ~10W | ~10W |
| **System (16 cards)** | | **257W** | **164W** |

#### 4.6.2 Critical Thermal Points

1. **Card-level isolated DC-DC (24V→24V)** — hottest single component on card (~3.3W waste at max continuous). Needs adequate PCB copper pour and airflow.
2. **Per-cell isolated DC-DC (B2412S-3WR2)** — 0.75W in SIP-4 package. Through-hole mounting provides good thermal path.
3. **LDO (TLV75901 in WSON-6)** — 0.25W in 2×2mm package. Θ_JA ≈ 60°C/W → 15°C rise. Comfortable.
4. **Card-level: 8 per-cell DC-DCs + card DC-DC in close proximity** — ~9.3W waste in a ~200×120mm card area. Board thermal relief + forced air mandatory.

#### 4.6.3 Cooling Strategy

| Method | Details |
|---|---|
| **Forced air** | Front-to-rear through enclosure, across card surfaces |
| **Fans** | 2–4× 120mm PWM fans on base board exhaust |
| **Fan controller** | CM5 I2C: PID loop on max(card temps, exhaust temp) |
| **Thermal shutdown** | Per-card: STM32H7 self-disables cells if T > 85°C. System: CM5 can kill 24V to individual slots via relay. |

**Airflow requirement:**

| Configuration | Waste Heat | CFM Required (ΔT=20°C) | Fans Needed |
|---|---|---|---|
| 4 cards typical | 38W | 1.1 CFM | 1× 120mm (low speed) |
| 10 cards typical | 96W | 2.7 CFM | 1× 120mm (low-medium) |
| 16 cards typical | 164W | 4.7 CFM | 1× 120mm (medium) |
| 16 cards max continuous | 257W | 7.3 CFM | 2× 120mm (low-medium) |

Formula: CFM = P_waste / (1.76 × ΔT), where 1.76 = air heat capacity factor in CFM·°C/W.

Typical 120mm fan: 40–100 CFM at moderate speed. **2× 120mm fans provide 80–200 CFM — substantial margin even at worst case.**

### 4.7 Per-Cell Component Status (v1 → v2)

| Component | v1 Part | v2 Part | Change Required | Priority |
|---|---|---|---|---|
| Isolated DC-DC | B1205S-2WR2 (12V→5V, 2W) | **YLPTEC B2412S-3WR2** (24V→12V, 3W, C5369517) | **Selected** — $1.95, 325 stock | **Resolved** |
| Digital Buck | TPS563201 (3A, SOT-23-6) | **TPS563201** (reuse, 12V input) | Proven, 12V within 4.5–17V range | **Resolved** |
| Digital LDO | TLV75901 (1A, 6V max in) | **TLV75901** (reuse) | Now works — buck max 5.5V < Vin 6V | **Resolved** |
| ~~Pi Filter~~ | ~~YNR4030-101M + 2×10µF~~ | **Removed** | Inductor DCR causes unacceptable voltage drop at 1A; LDO PSRR sufficient | — |
| Current Sensor | INA185A2 + 100mΩ shunt | INA185A2 + **50mΩ** shunt | Shunt value change | P2 |
| Output Relay | HFD4/5-SR DPDT | Same | Verify coil supply from 12V domain | P2 |
| Control LDO | LDK220M-R (5V→3.3V) | **LDK220M-R** (12V→3.3V, Vin max 13.2V) | **Reuse** — 12V within range | **Resolved** |
| Buck DAC | MCP4725 (addr 0x61) | Same | — | — |
| LDO DAC | MCP4725 (addr 0x60) | Same | — | — |
| ADC | ADS1115 (16-bit, I2C) | **ADS131M04** (24-bit, SPI, 32kSPS) | **Upgrade** — 4ch simultaneous, 10× faster | **Upgrade** |
| GPIO Expander | TCA6408 (addr 0x20) | Same | — | — |
| I2C Isolator | ISO1640BDR | Same | I2C path for DACs + GPIO | — |
| SPI Isolator | — | **ISO7741FDBQR** (4ch, 3F+1R) | **New** — isolates SPI for ADS131M04 | **New** |

**Card-level components (new in v2):**

| Component | Part | Function | Notes |
|---|---|---|---|
| Card-level isolated DC-DC | TDK20-24S24WH (or similar 24V→24V) | Backplane ↔ card isolation | 20W, proven in Peak 48ch |
| Card-level buck | TPSM84209RKHR | 24V_iso → 3.3V for MCU domain | Integrated inductor, 2.5A |
| Discrete Ethernet transformer | TBD | Ethernet PHY isolation | Required since Ethernet passes through backplane |
| UART digital isolator | TBD | UART isolation for card programming | Backplane routes UART via slot mux |
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

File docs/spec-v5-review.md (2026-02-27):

# CellSim v2 Spec v5 — Design Review

**Date:** 2026-02-26
**Reviewer:** Claude
**Scope:** Review of spec changes: 16-slot reduction, pi filter removal, output path resistance spec, backplane calibration relay mux

---

## Changes Applied

1. **Slot count 20 → 16** — Updated throughout all sections (§1–§12)
2. **Pi filter removed** — Stage 4 deleted, stages renumbered, power path diagrams updated, component table marked
3. **Output path resistance spec** — New §4.2.6 with ≤200 mΩ / ≤200 mV @1A budget
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

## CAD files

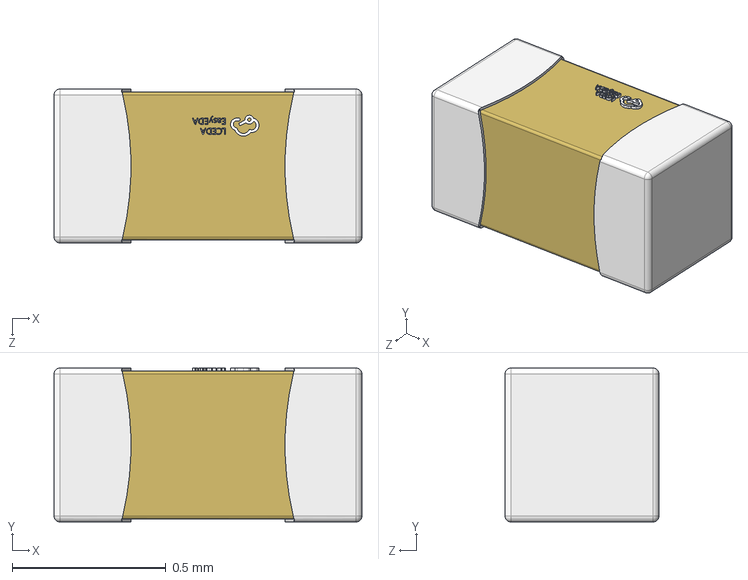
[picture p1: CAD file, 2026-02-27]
elec/cell-card/parts/CCTC_TCC0402C0G100J500AT/C0402_L1.0-W0.5-H0.5.step
1.00 x 0.5 x 0.5 mm

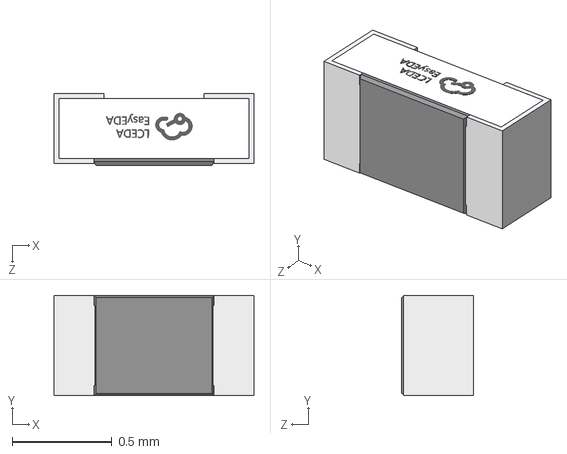
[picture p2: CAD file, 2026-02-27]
elec/cell-card/parts/FOJAN_FRC0402F1503TS/R0402_L1.0-W0.5-H0.4.step
1.00 x 0.501 x 0.36 mm

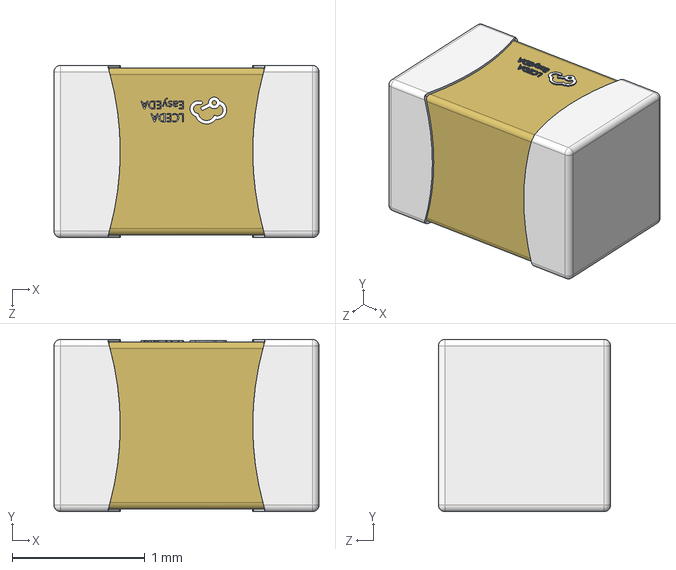
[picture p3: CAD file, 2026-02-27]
elec/cell-card/parts/Samsung_Electro_Mechanics_CL21A226MAQNNNE/C0805_L2.0-W1.3-H1.3.step
2.00 x 1.30 x 1.30 mm

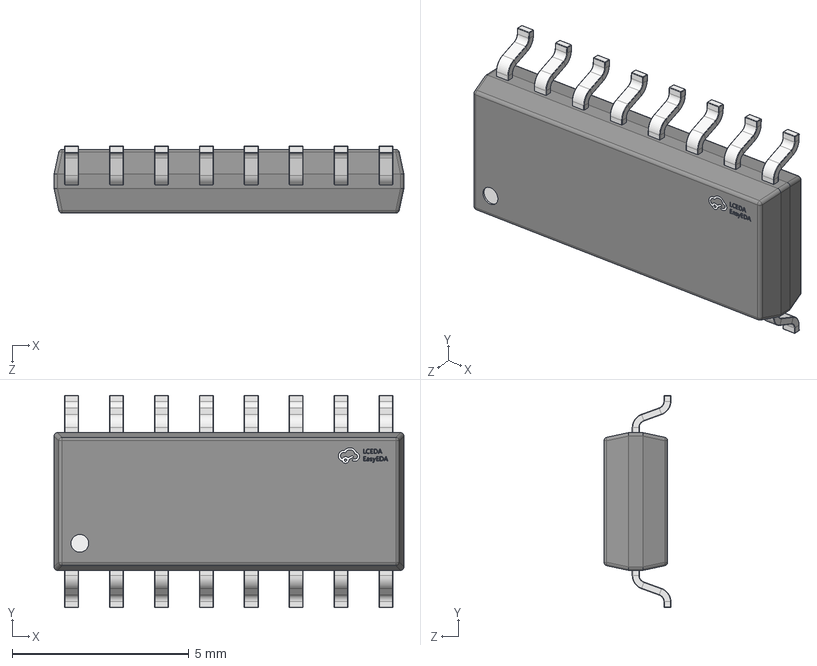
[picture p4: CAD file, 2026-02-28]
elec/cell-card/parts/Texas_Instruments_SN74HC368DRG4/SOIC-16_L9.9-W3.9-H1.8-LS6.0-P1.27.step
9.90 x 6.01 x 1.90 mm

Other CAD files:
elec/cell-card/parts/UNI_ROYAL_0603WAF1002T5E/R0603.STEP
elec/cell-card/parts/UNI_ROYAL_0805W4F500MT5E/R0805_L2.0-W1.3-H0.6.step
elec/packages/buttons/parts/ALPSALPINE_SKRPACE010/KEY-SMD_4P-L4.2-W3.2-H2.5-LS4.6-P2.2.step
elec/packages/buttons/parts/ALPSALPINE_SKTDLDE010/KEY-SMD_SKTDLDE010.step
elec/packages/buttons/parts/UNI_ROYAL_0603WAF1002T5E/R0603.STEP
elec/packages/cellsim-regulators/parts/UNI_ROYAL_0603WAF1002T5E/R0603.STEP
elec/packages/cellsim-regulators/parts/UNI_ROYAL_0603WAF1802T5E/R0603.STEP
elec/packages/indicator-leds/parts/Diodes_Incorporated_B230A_13_F/SMA_L4.4-W2.6-LS5.0-RD.step
elec/packages/indicator-leds/parts/Hubei_KENTO_Elec_Blue_light_0603/LED0603-RD-YELLOW.STEP
elec/packages/indicator-leds/parts/Hubei_KENTO_Elec_KT_0603G/LED0603-RD-YELLOW.STEP
elec/packages/indicator-leds/parts/Hubei_KENTO_Elec_KT_0603R/LED0603-RD-YELLOW.STEP
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

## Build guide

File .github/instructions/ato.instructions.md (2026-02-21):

---
description: ato is a declarative DSL to design electronics (PCBs) with.
applyTo: *.ato, ato.yaml
---

ato is a declarative DSL to design electronics (PCBs) with.
It is part of the atopile project.
Atopile is run by the vscode/cursor/windsurf extension.
The CLI (which is invoked by the extension) actually builds the project.

# Not available in ato

- if statements
- while loops
- functions (calls or definitions)
- classes
- objects
- exceptions
- generators

# Ato Syntax

ato sytax is heavily inspired by Python, but fully declarative.
ato thus has no procedural code, and no side effects.

## Examples of syntax

```ato
#pragma text
#pragma func("X")
# enable for loop syntax feature:
#pragma experiment("FOR_LOOP)

# --- Imports ---
# Standard import (newline terminated)
import ModuleName

# Import with multiple modules (newline terminated)
import Module1, Module2.Submodule

# Import from a specific file/source (newline terminated)
from "path/to/source.ato" import SpecificModule

# Multiple imports on one line (semicolon separated)
import AnotherModule; from "another/source.ato" import AnotherSpecific

# Deprecated import form (newline terminated)
# TODO: remove when unsupported
import DeprecatedModule from "other/source.ato"

# --- Top-level Definitions and Statements ---

pass
pass;

"docstring-like statement"
"docstring-like statement";

top_level_var = 123

# Compound statement
pass; another_var = 456; "another docstring"

# Block definitions
component MyComponent:
    # Simple statement inside block (newline terminated)
    pass

    # Multiple simple statements on one line (semicolon separated)
    pass; internal_flag = True

module AnotherBaseModule:
    pin base_pin
    base_param = 10

interface MyInterface:
    pin io

module DemoModule from AnotherBaseModule:
    # --- Declarations ---
    pin p1              # Pin declaration with name
    pin 1               # Pin declaration with number
    pin "GND"           # Pin declaration with string
    signal my_signal    # Signal definition
    a_field: AnotherBaseModule      # Field declaration with type hint

    # --- Assignments ---
    # Newline terminated:
    internal_variable = 123

    # Semicolon separated on one line:
    var_a = 1; var_b = "string"

    # Cumulative assignment (+=, -=) - Newline terminated
    value = 1
    value += 1; value -= 1

    # Set assignment (|=, &=) - Newline terminated
    flags |= 1; flags &= 2

    # --- Connections ---
    p1 ~ base_pin
    mif ~> bridge
    mif ~> bridge ~> bridge
    mif ~> bridge ~> bridge ~> mif
    bridge ~> mif
    mif <~ bridge
    mif <~ bridge <~ bridge
    mif <~ bridge <~ bridge <~ mif
    bridge <~ mif

    # Semicolon separated on one line:
    p_multi1 ~ my_signal; p_multi2 ~ sig_multi1

    # --- Retyping ---
    instance.x -> AnotherBaseModule

    # --- Instantiation ---
    instance = new MyComponent
    container = new MyComponent[10]
    templated_instance_a = new MyComponent
    templated_instance_b = new MyComponent<int_=1>
    templated_instance_c = new MyComponent<float_=2.5>
    templated_instance_d = new MyComponent<string_="hello">
    templated_instance_e = new MyComponent<int_=1, float_=2.5, string_="hello">
    templated_instance_f = new MyComponent<int_=1, float_=2.5, string_="hello", bool_=True>

    # Semicolon separated instantiations (via assignment):
    inst_a = new MyComponent; inst_b = new AnotherBaseModule

    # --- Traits ---
    trait trait_name
    trait trait_name<int_=1>
    trait trait_name<float_=2.5>
    trait trait_name<string_="hello">
    trait trait_name<bool_=True>
    trait trait_name::constructor
    trait trait_name::constructor<int_=1>

    # Semicolon separated on one line:
    trait TraitA; trait TraitB::constructor; trait TraitC<arg_=1>

    # --- Assertions ---
    assert x > 5V
    assert x < 10V
    assert 5V < x < 10V
    assert x >= 5V
    assert x <= 10V
    assert current within 1A +/- 10mA
    assert voltage within 1V +/- 10%
    assert resistance is 1kohm to 1.1kohm

    # Semicolon separated on one line:
    assert x is 1V; assert another_param is 2V

    # --- Loops ---
    for item in container:
        item ~ p1

    # For loop iterating over a slice
    for item in container[0:4]:
        pass
        item.value = 1; pass

    # For loop iterating over a list literal of field references
    for ref in [p1, x.1, x.GND]:
        pass

    # --- References and Indexing ---
    # Reference with array index assignment
    array_element = container[3]

    # --- Literals and Expressions ---
    # Integer
    int_val = 100
    neg_int_val = -50
    hex_val = 0xF1
    bin_val = 0b10
    oct_val = 0o10
    # Float
    float_val = 3.14
    # Physical quantities
    voltage: V = 5V
    resistance: ohm = 10kohm
    capacitance: F = 100nF
    # Bilateral tolerance
    tolerance_val = 1kohm +/- 10%
    tolerance_abs = 5V +/- 500mV
    tolerance_explicit_unit = 10A +/- 1A
    # Bounded quantity (range)
    voltage_range = 3V to 3.6V
    # Boolean
    is_enabled = True
    is_active = False
    # String
    message = "Hello inside module"

    # Arithmetic expressions
    sum_val = 1 + 2
    diff_val = 10 - 3ohm
    prod_val = 5 * 2mA
    div_val = 10V / 2kohm # Results in current
    power_val = 2**3
    complex_expr = (5 + 3) * 2 - 1
    flag_check = state | MASK_VALUE

    # Comparisons
    assert voltage within voltage_range
    assert length <= 5mm
    assert height >= 2mm

# --- Multi-line variations ---
pass; nested_var=1; another=2

complex_assignment = (
    voltage + resistance
    * capacitance
)

```

## G4 Grammar

```g4
parser grammar AtoParser;

options {
	superClass = AtoParserBase;
	tokenVocab = AtoLexer;
}

file_input: (NEWLINE | stmt)* EOF;

pragma_stmt: PRAGMA;

stmt: simple_stmts | compound_stmt | pragma_stmt;
simple_stmts:
	simple_stmt (SEMI_COLON simple_stmt)* SEMI_COLON? NEWLINE;
simple_stmt:
	import_stmt
	| dep_import_stmt
	| assign_stmt
	| cum_assign_stmt
	| set_assign_stmt
	| connect_stmt
	| directed_connect_stmt
	| retype_stmt
	| pin_declaration
	| signaldef_stmt
	| assert_stmt
	| declaration_stmt
	| string_stmt
	| pass_stmt
	| trait_stmt;

compound_stmt: blockdef | for_stmt;

blockdef: blocktype name blockdef_super? COLON block;
// TODO @v0.4 consider ()
blockdef_super: FROM type_reference;
// TODO @v0.4 consider removing component (or more explicit code-as-data)
blocktype: (COMPONENT | MODULE | INTERFACE);
block: simple_stmts | NEWLINE INDENT stmt+ DEDENT;

// TODO: @v0.4 remove the deprecated import form
dep_import_stmt: IMPORT type_reference FROM string;
import_stmt: (FROM string)? IMPORT type_reference (
		COMMA type_reference
	)*;

declaration_stmt: field_reference type_info;
field_reference_or_declaration:
	field_reference
	| declaration_stmt;
assign_stmt: field_reference_or_declaration '=' assignable;
cum_assign_stmt:
	field_reference_or_declaration cum_operator cum_assignable;
// TODO: consider sets cum operator
set_assign_stmt:
	field_reference_or_declaration (OR_ASSIGN | AND_ASSIGN) cum_assignable;
cum_operator: ADD_ASSIGN | SUB_ASSIGN;
cum_assignable: literal_physical | arithmetic_expression;

assignable:
	string
	| new_stmt
	| literal_physical
	| arithmetic_expression
	| boolean_;

retype_stmt: field_reference ARROW type_reference;

directed_connect_stmt
	: bridgeable ((SPERM | LSPERM) bridgeable)+; // only one type of SPERM per stmt allowed. both here for better error messages
connect_stmt: mif WIRE mif;
bridgeable: connectable;
mif: connectable;
connectable: field_reference | signaldef_stmt | pindef_stmt;

signaldef_stmt: SIGNAL name;
pindef_stmt: pin_stmt;
pin_declaration: pin_stmt;
pin_stmt: PIN (name | number_hint_natural | string);

new_stmt: NEW type_reference ('[' new_count ']')? template?;
new_count: number_hint_natural;

string_stmt:
	string; // the unbound string is a statement used to add doc-strings

pass_stmt:
	PASS; // the unbound string is a statement used to add doc-strings

list_literal_of_field_references:
	'[' (field_reference (COMMA field_reference)* COMMA?)? ']';

iterable_references:
	field_reference slice?
	| list_literal_of_field_references;

for_stmt: FOR name IN iterable_references COLON block;

assert_stmt: ASSERT comparison;

trait_stmt
	: TRAIT type_reference (DOUBLE_COLON constructor)? template?; // TODO: move namespacing to type_reference
constructor: name;
template: '<' (template_arg (COMMA template_arg)* COMMA?)? '>';
template_arg: name ASSIGN literal;

// Comparison operators --------------------
comparison: arithmetic_expression compare_op_pair+;

compare_op_pair:
	lt_arithmetic_or
	| gt_arithmetic_or
	| lt_eq_arithmetic_or
	| gt_eq_arithmetic_or
	| in_arithmetic_or
	| is_arithmetic_or;

lt_arithmetic_or: LESS_THAN arithmetic_expression;
gt_arithmetic_or: GREATER_THAN arithmetic_expression;
lt_eq_arithmetic_or: LT_EQ arithmetic_expression;
gt_eq_arithmetic_or: GT_EQ arithmetic_expression;
in_arithmetic_or: WITHIN arithmetic_expression;
is_arithmetic_or: IS arithmetic_expression;

// Arithmetic operators --------------------

arithmetic_expression:
	arithmetic_expression (OR_OP | AND_OP) sum
	| sum;

sum: sum (PLUS | MINUS) term | term;

term: term (STAR | DIV) power | power;

power: functional (POWER functional)?;

functional: bound | name '(' bound+ ')';

bound: atom;

// Primary elements ----------------

slice:
	'[' (slice_start? COLON slice_stop? (COLON slice_step?)?)? ']'
	// else [::step] wouldn't match
	| '[' ( DOUBLE_COLON slice_step?) ']';
slice_start: number_hint_integer;
slice_stop: number_hint_integer;
slice_step: number_hint_integer;

atom: field_reference | literal_physical | arithmetic_group;

arithmetic_group: '(' arithmetic_expression ')';

literal_physical:
	bound_quantity
	| bilateral_quantity
	| quantity;

bound_quantity: quantity TO quantity;
bilateral_quantity: quantity PLUS_OR_MINUS bilateral_tolerance;
quantity: number name?;
bilateral_tolerance: number_signless (PERCENT | name)?;

key: number_hint_integer;
array_index: '[' key ']';

// backwards compatibility for A.1
pin_reference_end: DOT number_hint_natural;
field_reference_part: name array_index?;
field_reference:
	field_reference_part (DOT field_reference_part)* pin_reference_end?;
type_reference: name (DOT name)*;
// TODO better unit
unit: name;
type_info: COLON unit;
name: NAME;

// Literals
literal: string | boolean_ | number;

string: STRING;
boolean_: TRUE | FALSE;
number_hint_natural: number_signless;
number_hint_integer: number;
number: (PLUS | MINUS)? number_signless;
number_signless: NUMBER;
```

# Most used library modules/interfaces (api of them)

```ato
interface Electrical:
    pass

interface ElectricPower:
    hv = new Electrical
    lv = new Electrical

module Resistor:
    resistance: ohm
    max_power: W
    max_voltage: V
    unnamed = new Electrical[2]

module Capacitor:
    capacitance: F
    max_voltage: V
    unnamed = new Electrical[2]

interface I2C:
    scl = new ElectricLogic
    sda = new ElectricLogic
    frequency: Hz
    address: dimensionless

interface ElectricLogic:
    line = new Electrical
    reference = new ElectricPower
```

For the rest use the atopile MCP server 
- `get_library_interfaces` to list interfaces
- `get_library_modules` to list modules
- `inspect_library_module_or_interface` to inspect the code

# Ato language features

## experimental features

Enable with `#pragma experiment("BRIDGE_CONNECT")`
BRIDGE_CONNECT: enables `p1 ~> resistor ~> p2` syntax
FOR_LOOP: enables `for item in container: pass` syntax
TRAITS: enables `trait trait_name` syntax
MODULE_TEMPLATING: enables `new MyComponent<param=literal>` syntax

## modules, interfaces, parameters, traits

A block is either a module, interface or component.
Components are just modules for code-as-data.
Interfaces describe a connectable interface (e.g Electrical, ElectricPower, I2C, etc).
A module is a block that can be instantiated.
Think of it as the ato equivalent of a class.
Parameters are variables for numbers and they work with constraints.
E.g `resistance: ohm` is a parameter.
Constrain with `assert resistance within 10kohm +/- 10%`.
It's very important to use toleranced values for parameters.
If you constrain a resistor.resistance to 10kohm there won't be a single part found because that's a tolerance of 0%.

Traits mark a module to have some kind of functionality that can be used in other modules.
E.g `trait has_designator_prefix` is the way to mark a module to have a specific designator prefix that will be used in the designator field in the footprint.

## connecting

You can only connect interfaces of the same type.
`resistor0.unnamed[0] ~ resistor0.unnamed[0]` is the way to connect two resistors in series.
If a module has the `can_bridge` trait you can use the sperm operator `~>` to bridge the module.
`led.anode ~> resistor ~> power.hv` connects the anode in series with the resistor and then the resistor in series with the high voltage power supply.

## for loop syntax

`for item in container: pass` is the way to iterate over a container.

# Ato CLI

## How to run

You run ato commands through the MCP tool.

## Packages

Packages can be found on the ato registry.
To install a package you need to run `ato add <PACKAGE_NAME>`.
e.g `ato install atopile/addressable-leds`
And then can be imported with `from "atopile/addressable-leds/sk6805-ec20.ato" import SK6805_EC20_driver`.
And used like this:

```ato
module MyModule:
    led = new SK6805_EC20_driver
```

## Footprints & Part picking

Footprint selection is done through the part choice (`ato create part` auto-generates ato code for the part).
The `pin` keyword is used to build footprint pinmaps so avoid using it outside of `component` blocks.
Preferrably use `Electrical` interface for electrical interfaces.
A lot of times it's actually `ElectricLogic` for things like GPIOs etc or `ElectricPower` for power supplies.

Passive modules (Resistors, Capacitors) are picked automatically by the constraints on their parameters.
To constrain the package do e.g `package = "0402"`.
To explictly pick a part for a module use `lcsc = "<LCSC_PART_NUMBER>"`.

# Creating a package

Package generation process:

Review structure of other pacakges.

1. Create new Directory in 'packages/packages' with naming convention '<vendor>-<device>' eg 'adi-adau145x'
2. create an ato.yaml file in the new directory with the following content:

```yaml
requires-atopile: '^0.9.0'

paths:
    src: '.'
    layout: ./layouts

builds:
    default:
        entry: <device>.ato:<device>_driver
    example:
        entry: <device>.ato:Example
```

3. Create part using tool call 'search_and_install_jlcpcb_part'
4. Import the part into the <device>.ato file
5. Read the datasheet for the device
6. Find common interfaces in the part eg I2C, I2S, SPI, Power

7. Create interfaces and connect them

power interfaces:
power*<name> = new ElectricPower
power*<name>.required = True # If critical to the device
assert power\*<name>.voltage within <minimum*operating_voltage>V to <maximum_operating_voltage>V
power*<name>.vcc ~ <device>.<vcc pin>
power\_<name>.gnd ~ <device>.<gnd pin>

i2c interfaces:
i2c = new I2C
i2c.scl.line ~ <device>.<i2c scl pin>
i2c.sda.line ~ <device>.<i2c sda pin>

spi interfaces:
spi = new SPI
spi.sclk.line ~ <device>.<spi sclk pin>
spi.mosi.line ~ <device>.<spi mosi pin>
spi.miso.line ~ <device>.<spi miso pin>

8. Add decoupling capacitors

looking at the datasheet, determine the required decoupling capacitors

eg: 2x 100nF 0402:

power_3v3 = new ElectricPower

# Decoupling power_3v3

power_3v3_caps = new Capacitor[2]
for capacitor in power_3v3_caps:
capacitor.capacitance = 100nF +/- 20%
capacitor.package = "0402"
power_3v3.hv ~> capacitor ~> power_3v3.lv

9. If device has pin configurable i2c addresses

If format is: <n x fixed address bits><m x pin configured address bits>
use addressor module:

- Use `Addressor<address_bits=N>` where **N = number of address pins**.
- Connect each `address_lines[i].line` to the corresponding pin, and its `.reference` to a local power rail.
- Set `addressor.base` to the lowest possible address and `assert addressor.address is i2c.address`.

10. Create a README.md

# <Manufacturer> <Manufacturer part number> <Short description>

## Usage

```ato
<copy in example>

```

## Contributing

Contributions to this package are welcome via pull requests on the GitHub repository.

## License

This atopile package is provided under the [MIT License](https://opensource.org/license/mit/).

11. Connect high level interfaces directly in example:

eg:

i2c = new I2C
power = new ElectricPower
sensor = new Sensor

i2c ~ sensor.i2c
power ~ sensor.power_3v3

# Additional Notes & Gotchas (generic)

- Multi-rail devices (VDD / VDDIO, AVDD / DVDD, etc.)

    - Model separate `ElectricPower` interfaces for each rail (e.g. `power_core`, `power_io`).
    - Mark each `.required = True` if the device cannot function without it, and add voltage assertions per datasheet.

- Optional interfaces (SPI vs I²C)

    - If the device supports multiple buses, pick one for the initial driver. Leave unused bus pins as `ElectricLogic` lines or expose a second interface module later.

- Decoupling guidance

    - If the datasheet shows multiple caps, model the **minimum required** set so the build passes; you can refine values/packages later.

- File / directory layout recap
    - `<vendor>-<device>/` – package root
    - `ato.yaml` – build manifest (include `default` **and** `example` targets)
    - `<device>.ato` – driver + optional example module
    - `parts/<MANUFACTURER_PARTNO>/` – atomic part + footprint/symbol/step files

These tips should prevent common "footprint not found", "pin X missing", and build-time path errors when you add new devices.

# Vibe coding a project

If the user gives you high level description of the project, use the following guide:

# How LLMs can design electronics:

#1 Rule: USE THE TOOLS. If the tools dont work, dont freak out, you are probably using them wrong. Ask for help if you get stuck.

Top level design

1. Research available packages relevant to the user requests using 'find_packages'
2. Inspect promising packages using 'inspect_package'
3. Propose packages to use for project and architucture to user, revise if needed
4. Install needed packages using 'install_package'
5. Import packages into main file
6. Create instances of packages in main module

## Power

1. Review for each package the required voltage and current (current may not be provided, use judement if nessesary)
2. Determine the power rails that need to be generated and a suitable tollerance (typically ~3-5% is acceptable)
3. Determine the input power source, typically a battery, USB connector or other power connector (eg XT30) and install relevant package
4. Find suitable regulators:
   a) if input voltage > required voltage and current is low, use an LDO package
   b) if input voltage > required voltage and current is high, use buck converter
   c) if input votlage < required voltage, use a boost converter
   d) if input voltage can be both less than or greater than input voltage, use buck boost (eg battery powered device that needs 3v3)
5. If battery powered, add charger package

Typical power architucture example with LDO:

- USB input power
- Low current output (eg microcontroller)

from "atopile/ti-tlv75901/ti-tlv75901.ato" import TLV75901_driver
from "atopile/usb-connectors/usb-connectors.ato" import USBCConn

module App:

    # Rails
    power_5v = new Power
    power_3v3 = new Power

    # Components
    ldo = new TLV75901_driver
    usb_connector = new USBCConn

    # Connections
    usb_connector.power ~ power_vbus
    power_vbus ~> ldo ~> power_3v3

## Communicaions

1. Review packages required interfaces, typically i2c, spi or ElectricLogics
2. Find suitable pins on the controller, typically a microcontroller or Linux SOC
3. Connect interfaces eg micro.i2c[0] ~ sensor.i2c

## Development process notes

- After making changes, be sure to use 'build_project' to update the PCB
- Builds will often generate errors/warnings, these should be reviewed and fixed
- Prioritize pacakges from 'atopile' over other packages

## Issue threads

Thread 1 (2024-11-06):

Increase cell input voltage to 9V

napowderly, 2024-11-06:
Unable to output more than 4.3V, I believe this is due to minimum dropout across the buck and LDO regulators.
Simple solution is to increase the input to 9V, limitation is the LDO is only capable to 5.5V input, might need to switch for something that could in worst case survive 9V input.

mawildoer, 2024-11-06:
Isn't there a buck in-between? If so, then limiting the buck's output voltage could also solve it

napowderly, 2024-11-06:
Yeah there is a buck, could potentially do that, its slightly complicated by the DAC control of the feedback node.

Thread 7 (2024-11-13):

Ethernet

napowderly, 2024-11-13:
Add an RJ45 connector + ethernet to spi converter (perhaps wiznet)

napowderly, 2024-11-30:
Addressed in release V0.1.0!

Closed 2024-11-30.

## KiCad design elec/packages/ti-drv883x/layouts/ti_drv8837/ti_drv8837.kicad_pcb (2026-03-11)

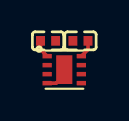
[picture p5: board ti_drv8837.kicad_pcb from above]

Board: 2 copper layers, 3 parts (0 on the bottom side), 3 nets.

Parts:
C1, C2: 100nF; C0402
U1: WSON-8_L2.0-W2.0-P0.50-TL-EP

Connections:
hv: C1.1, U1.8
lv: C1.2, C2.2, U1.4, U1.9
motor_power_decoupling_capacitor-power-hv: C2.1, U1.1

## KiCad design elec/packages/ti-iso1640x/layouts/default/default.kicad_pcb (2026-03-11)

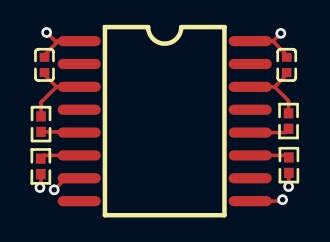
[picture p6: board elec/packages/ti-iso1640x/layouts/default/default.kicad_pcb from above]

Board: 2 copper layers, 7 parts (0 on the bottom side), 6 nets.

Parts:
C1, C2: 100nF; C0402
R1, R2, R3, R4: 10kΩ; R0402
U1: SOIC-16_L10.3-W7.4-P1.27-LS10.3-BL

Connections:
SCL: R1.2, R2.2, U1.6, U1.11
SDA: R3.2, R4.2, U1.5, U1.12
decoupling_cap_side2-power-hv: C2.1, R2.1, R4.1, U1.14
decoupling_cap_side2-power-lv: C2.2, U1.9, U1.16
hv: C1.1, R1.1, R3.1, U1.3
lv: C1.2, U1.1, U1.7

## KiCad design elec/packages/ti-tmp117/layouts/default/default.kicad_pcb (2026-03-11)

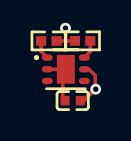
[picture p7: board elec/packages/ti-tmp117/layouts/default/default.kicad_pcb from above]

Board: 2 copper layers, 4 parts (0 on the bottom side), 4 nets.

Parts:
C1: 100nF; C0402
R1, R2: 10kΩ; R0402
U1: WSON-6_L2.0-W2.0-P0.65-TL-EP

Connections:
SCL: R1.1, U1.1
SDA: R2.1, U1.6
hv: C1.1, R1.2, R2.2, U1.5
lv: C1.2, U1.2, U1.4, U1.7

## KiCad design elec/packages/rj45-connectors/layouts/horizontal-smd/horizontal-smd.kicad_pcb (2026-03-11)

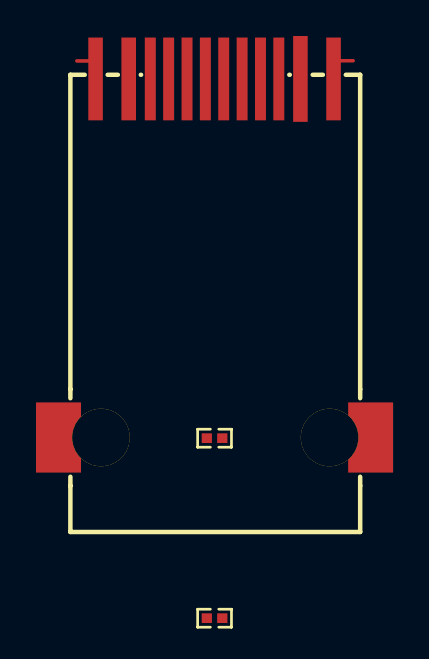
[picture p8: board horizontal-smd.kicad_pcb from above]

Board: 2 copper layers, 3 parts (0 on the bottom side), 4 nets.

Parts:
R1, R2: 470Ω; R0402
RJ1: RJ45-SMD_BS-R250210

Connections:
CT: RJ1.3, RJ1.4
L_LED_Gpos: R2.2, RJ1.12
R_LEDYpos: R1.2, RJ1.9
lv: RJ1.8, RJ1.10, RJ1.11, RJ1.13, RJ1.14

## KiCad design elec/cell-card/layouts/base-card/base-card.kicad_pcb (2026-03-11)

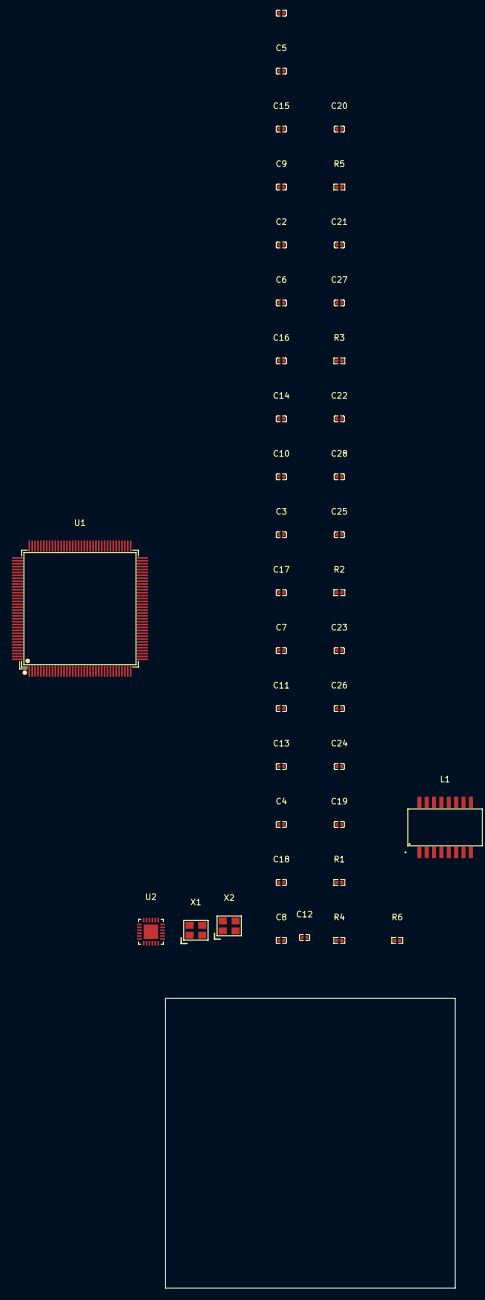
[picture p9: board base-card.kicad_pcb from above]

Board: 2 copper layers, 50.0 x 50.0 mm, 39 parts (0 on the bottom side), 27 nets, no tracks yet.

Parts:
C1, C2, C3, C4, C5, C6, C7, C8, C9, C10, C11, C12, C18, C19, C20, C21, C22, C23: 100nF; C0402
C13, C14, C27, C28: 18pF; C0402
C15, C16: 2.2µF; C0402
C17, C24, C25: 1µF; C0402
C26: 470pF; C0402
L1: SMD-16_L12.7-W7.2-P1.27-LS9.5-BL
R1, R2: 49.9Ω; R0402
R3, R5: 100kΩ; R0402
R4: 12.1kΩ; R0402
R6: 10kΩ; R0402
U1: LQFP-144_L20.0-W20.0-P0.50-LS22.0-BL
U2: QFN-24_L4.0-W4.0-P0.50-TL-EP2.5
X1, X2: OSC-SMD_4P-L3.2-W2.5-BL_SIT8008BI

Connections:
ETH_LED_LINK: R5.1, U2.3
MDC: U1.42, U2.13
RBIAS: R4.1, U2.24
RTC: L1.7, R1.1
TCT: L1.2, R2.1
TXEN: U1.70, U2.16
XIN: C13.1, U1.23, X1.1
XOUT: C14.1, U1.24, X1.3
ethernet-ETH_N0_N: L1.8, U2.22
ethernet-ETH_N1_N: L1.3, U2.20
ethernet-ETH_P0_P: L1.6, U2.23
ethernet-ETH_P1_P: L1.1, U2.21
hv: C19.1, L1.10, L1.15
line: U1.43, U2.11, U2.12
lv: C1.2, C2.2, C3.2, C4.2, C5.2, C6.2, C7.2, C8.2, C9.2, C10.2, C11.2, C12.2, C13.2, C14.2, C15.2, C16.2, C17.2, C18.2, C19.2, C20.2, C21.2, C22.2, C23.2, C24.2, C25.2, C26.2, C27.2, C28.2, R3.2, R4.2, R5.2, U1.16, U1.31, U1.38, U1.51, U1.61, U1.83, U1.94, U1.107, U1.120, U1.130, U2.25, X1.2, X1.4, X2.2, X2.4
nINT_REFCLKO: U1.35, U2.14
nRST: R6.1, U1.40, U2.15
phy-rmii-line: R3.1, U1.69, U2.10
phy-rmii-line-1: U1.73, U2.17
phy-rmii-line-2: U1.74, U2.18
phy-rmii-line-3: U1.44, U2.8
phy-rmii-line-4: U1.45, U2.7
vcap_caps[1]-power-hv: C15.1, C16.1, U1.71, U1.106
vddcr_caps[1]-power-hv: C25.1, C26.1, U2.6
vref_caps[1]-power-hv: C1.1, C2.1, C3.1, C4.1, C5.1, C6.1, C7.1, C8.1, C9.1, C10.1, C11.1, C12.1, C17.1, C18.1, C20.1, C21.1, C22.1, C23.1, C24.1, R1.2, R2.2, R6.2, U1.17, U1.30, U1.32, U1.33, U1.39, U1.52, U1.62, U1.72, U1.84, U1.95, U1.108, U1.121, U1.131, U1.144, U2.1, U2.9, U2.19
xtal_caps[0]-power-hv: C27.1, U2.5, X2.1
xtal_caps[1]-power-hv: C28.1, U2.4, X2.3

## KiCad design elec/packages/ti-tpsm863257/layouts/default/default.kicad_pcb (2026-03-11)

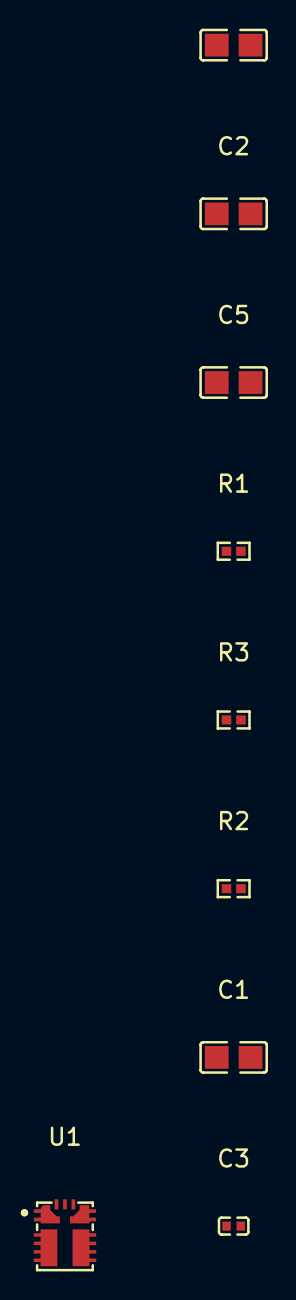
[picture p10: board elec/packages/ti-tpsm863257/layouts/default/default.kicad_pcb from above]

Board: 2 copper layers, 9 parts (0 on the bottom side), 5 nets, no tracks yet.

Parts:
C1, C2: 10µF; C0805
C3: 100nF; C0402
C4, C5: 22µF; C0805
R1: 10kΩ; R0402
R2: 100kΩ; R0402
R3: 73.2kΩ; R0402
U1: QFN-7_L4.0-W3.3_TPSM863257RDXR

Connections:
FB: R1.1, R3.2, U1.7
PG: R2.2, U1.5
c_out[1]-power-hv: C4.1, C5.1, R2.1, R3.1, U1.3
hv: C1.1, C2.1, C3.1, U1.1
lv: C1.2, C2.2, C3.2, C4.2, C5.2, R1.2, U1.4

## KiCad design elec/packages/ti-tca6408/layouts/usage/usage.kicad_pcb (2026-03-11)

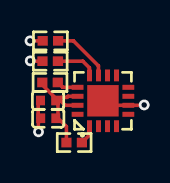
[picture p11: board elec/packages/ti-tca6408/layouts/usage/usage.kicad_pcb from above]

Board: 2 copper layers, 7 parts (0 on the bottom side), 6 nets.

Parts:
C1, C2: 100nF; C0402
R1, R2, R3, R4: 4.7kΩ; R0402
U1: QFN-16_L3.0-W3.0-P0.50-BL-EP1.7

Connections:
SCL: R2.1, U1.12
SDA: R3.1, U1.13
hv: C1.1, C2.1, R1.1, R2.2, R3.2, R4.1, U1.14, U1.15
lv: C1.2, C2.2, U1.6, U1.17
nINT: R1.2, U1.11
nRESET: R4.2, U1.1

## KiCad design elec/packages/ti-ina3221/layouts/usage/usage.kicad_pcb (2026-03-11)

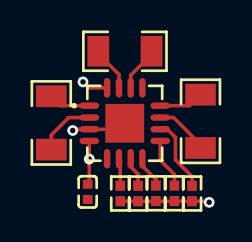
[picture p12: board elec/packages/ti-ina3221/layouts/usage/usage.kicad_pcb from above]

Board: 2 copper layers, 10 parts (0 on the bottom side), 11 nets.

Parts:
C1: 100nF; C0402
R1, R2, R6, R7, R8: 10kΩ; R0402
R3, R4, R5: 150mΩ; R1206
U1: QFN-16_L4.0-W4.0-P0.65-TL-EP2.2

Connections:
CRITICAL: R6.2, U1.9
PV: R7.2, U1.10
SCL: R1.2, U1.6
SDA: R2.2, U1.7
WARNING: R8.2, U1.8
hv: C1.1, R1.1, R2.1, R6.1, R7.1, R8.1, U1.4, U1.16
lv: C1.2, U1.3, U1.5, U1.17
power_5v_P: R3.1, R4.1, R5.1, U1.2, U1.12, U1.15
power_N: R3.2, U1.11
sinks[1]-power-power_N: R4.2, U1.14
sinks[2]-power-power_N: R5.2, U1.1

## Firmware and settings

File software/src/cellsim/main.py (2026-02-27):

"""
CellSim v2 — CM5 Orchestration Server

FastAPI REST server running on the Raspberry Pi CM5.
Discovers cards on the internal Ethernet network, aggregates measurements,
and exposes a unified API for cell control, calibration, monitoring, and
autonomous bringup.

Architecture:
    CM5 eth0 (uplink) -> serves REST API to lab network / host PC
    CM5 eth1 (internal) -> communicates with cards over private 10.0.0.x subnet
    Cards are never directly exposed to the external network.
"""

from __future__ import annotations

import asyncio
import logging
import time
from contextlib import asynccontextmanager

from fastapi import Depends, FastAPI, HTTPException, WebSocket, WebSocketDisconnect
from fastapi.responses import StreamingResponse

from cellsim.app_state import AppState
from cellsim.bringup import BringupOrchestrator
from cellsim.card_manager import CardManager
from cellsim.deps import (
    get_app_state,
    get_card_manager,
    get_slot_mux,
    get_slot_power,
    validate_slot_id,
)
from cellsim.models import (
    CELLS_PER_CARD,
    NUM_SLOTS,
    BringupRequest,
    BringupStatus,
    CellRequest,
    ErrorResponse,
    FlashRequest,
    HealthResponse,
    KelvinMode,
    SlotPowerRequest,
    SlotPowerState,
    SystemRequest,
    SystemState,
)
from cellsim.protocol import MeasurementPacket
from cellsim.slot_mux import SlotMux
from cellsim.slot_power import SlotPowerManager
from cellsim.uart_flasher import UartFlasher

logger = logging.getLogger(__name__)

_start_time: float = 0.0


@asynccontextmanager
async def lifespan(app: FastAPI):
    """Startup: initialize hardware, discover cards. Shutdown: clean up."""
    global _start_time
    _start_time = time.monotonic()

    state = AppState()
    app.state.cellsim = state

    try:
        await state.startup()
    except Exception:
        logger.exception("Startup failed — running in degraded mode")

    yield

    await state.shutdown()


app = FastAPI(
    title="CellSim v2",
    version="2.0.0-dev",
    lifespan=lifespan,
    responses={503: {"model": ErrorResponse}},
)


# ── Health ──

@app.get("/api/health")
async def health(state: AppState = Depends(get_app_state)) -> HealthResponse:
    """Liveness / readiness probe."""
    online = sum(1 for c in state.card_manager.cards.values() if c.online)
    return HealthResponse(
        uptime=time.monotonic() - _start_time,
        cards_online=online,
        e_stop_active=state.slot_power.get_estop_state(),
    )


# ── System State ──

@app.get("/api/state")
async def get_state(state: AppState = Depends(get_app_state)) -> SystemState:
    """Get complete system state: all cards, cells, thermistors, thermal."""
    from cellsim.models import CardState, CellState, Measurement, ThermalState

    cards_out = []
    cm = state.card_manager

    for slot_id, conn in cm.cards.items():
        if not conn.online:
            continue

        cells = []
        meas = cm.measurements.get(slot_id)
        if meas and meas.cells:
            for i, c in enumerate(meas.cells):
                cells.append(CellState(
                    id=slot_id * CELLS_PER_CARD + i,
                    card_slot=slot_id,
                    cell_index=i,
                    voltage_setpoint=c.setpoint_v,
                    voltage_measured=Measurement(value=c.voltage_v),
                    current_measured=Measurement(value=c.current_a),
                    cell_temperature=c.temp_c,
                    enabled=c.output_enabled,
                    output_relay_enabled=c.relay_closed,
                    kelvin_mode=KelvinMode.FOUR_WIRE if c.four_wire else KelvinMode.TWO_WIRE,
                    self_test_passed=bool(c.flags & 0x10),
                ))

        board_temp = meas.mcu_temp_c if meas else 0.0
        input_v = meas.vin_v if meas else 0.0

        cards_out.append(CardState(
            slot=slot_id,
            card_id=conn.card_id,
            card_type=conn.card_type,
            firmware_version=conn.firmware_version,
            ip_address=conn.ip_address,
            cells=cells,
            board_temperature=board_temp,
            input_voltage=input_v,
            online=conn.online,
        ))

    loop = asyncio.get_running_loop()
    estop = await loop.run_in_executor(None, state.slot_power.get_estop_state)

    # Aggregate thermal from all cards
    card_temps = {c.slot: c.board_temperature for c in cards_out}
    thermal = ThermalState(card_temperatures=card_temps)

    return SystemState(
        cards=cards_out,
        thermal=thermal,
        total_cells=sum(len(c.cells) for c in cards_out),
        uptime=time.monotonic() - _start_time,
        e_stop_active=estop,
    )


@app.post("/api/config")
async def set_config(
    request: SystemRequest,
    state: AppState = Depends(get_app_state),
):
    """Bulk configure cells and thermistors."""
    from cellsim.protocol import Cmd, encode_enable_output, encode_set_mode, encode_set_voltage

    cm = state.card_manager
    errors = []

    for cell_req in request.cells:
        slot_id = cell_req.id // CELLS_PER_CARD
        cell_idx = cell_req.id % CELLS_PER_CARD

        try:
            if cell_req.voltage_setpoint is not None:
                mv = int(cell_req.voltage_setpoint * 1000)
                await cm.send_command(slot_id, Cmd.SET_VOLTAGE, cell_idx, encode_set_voltage(mv))

            if cell_req.output_relay_enabled is not None:
                await cm.send_command(
                    slot_id, Cmd.ENABLE_OUTPUT, cell_idx,
                    encode_enable_output(cell_req.output_relay_enabled),
                )

            if cell_req.kelvin_mode is not None:
                four_wire = cell_req.kelvin_mode == KelvinMode.FOUR_WIRE
                await cm.send_command(
                    slot_id, Cmd.SET_MODE, cell_idx, encode_set_mode(four_wire)
                )
        except (ConnectionError, ValueError) as e:
            errors.append({"cell_id": cell_req.id, "error": str(e)})

    return {"accepted": len(request.cells), "errors": errors}


@app.post("/api/config/cell")
async def set_cell_config(
    request: CellRequest,
    state: AppState = Depends(get_app_state),
):
    """Configure a single cell."""
    from cellsim.protocol import Cmd, encode_enable_output, encode_set_mode, encode_set_voltage

    slot_id = request.id // CELLS_PER_CARD
    cell_idx = request.id % CELLS_PER_CARD
    cm = state.card_manager

    try:
        if request.voltage_setpoint is not None:
            mv = int(request.voltage_setpoint * 1000)
            await cm.send_command(slot_id, Cmd.SET_VOLTAGE, cell_idx, encode_set_voltage(mv))

        if request.output_relay_enabled is not None:
            await cm.send_command(
                slot_id, Cmd.ENABLE_OUTPUT, cell_idx,
                encode_enable_output(request.output_relay_enabled),
            )

        if request.kelvin_mode is not None:
            four_wire = request.kelvin_mode == KelvinMode.FOUR_WIRE
            await cm.send_command(
                slot_id, Cmd.SET_MODE, cell_idx, encode_set_mode(four_wire)
            )
    except ConnectionError as e:
        raise HTTPException(502, f"Card communication failed: {e}")

    return {"cell_id": request.id, "accepted": True}


# ── Card Management ──

@app.get("/api/cards")
async def get_cards(state: AppState = Depends(get_app_state)):
    """Get card discovery status, firmware versions, health."""
    return [
        {
            "slot_id": c.slot_id,
            "card_type": c.card_type,
            "card_id": c.card_id,
            "ip_address": c.ip_address,
            "firmware_version": c.firmware_version,
            "online": c.online,
            "last_seen": c.last_seen,
        }
        for c in state.card_manager.cards.values()
    ]


# ── Self-Test & Calibration ──

@app.post("/api/self-test")
async def self_test(state: AppState = Depends(get_app_state)):
    """Run BIST on all online cards. Returns per-card results."""
    from cellsim.protocol import Cmd, Status

    cm = state.card_manager
    results = {}

    for slot_id, card in cm.cards.items():
        if not card.online:
            continue

        try:
            status, payload = await cm.send_command(slot_id, Cmd.SELF_TEST, timeout=10.0)
            results[slot_id] = {
                "status": status.name,
                "passed": status == Status.OK,
                "payload": payload.hex() if payload else None,
            }
        except ConnectionError as e:
            results[slot_id] = {"status": "CONNECTION_ERROR", "passed": False, "error": str(e)}

    return {"results": results}


@app.post("/api/calibration")
async def calibrate(state: AppState = Depends(get_app_state)):
    """Run calibration on all online cards."""
    from cellsim.protocol import Cmd, Status

    cm = state.card_manager
    results = {}

    for slot_id, card in cm.cards.items():
        if not card.online:
            continue

        try:
            status, payload = await cm.send_command(slot_id, Cmd.CALIBRATE, timeout=30.0)
            results[slot_id] = {
                "status": status.name,
                "payload": payload.hex() if payload else None,
            }
        except ConnectionError as e:
            results[slot_id] = {"status": "CONNECTION_ERROR", "error": str(e)}

    return {"results": results}


# ── Thermal ──

@app.get("/api/thermal")
async def get_thermal(state: AppState = Depends(get_app_state)):
    """Get temperatures from measurement stream and bus status."""
    from cellsim.models import ThermalState

    cm = state.card_manager
    card_temps = {}
    for slot_id, meas in cm.measurements.items():
        card_temps[slot_id] = meas.mcu_temp_c

    loop = asyncio.get_running_loop()
    bus = await loop.run_in_executor(None, state.slot_power.read_bus_status)

    return ThermalState(
        card_temperatures=card_temps,
    ).model_dump()


# ── Firmware ──

@app.post("/api/firmware/upload")
async def upload_firmware(state: AppState = Depends(get_app_state)):
    """Push firmware update to cards over Ethernet (SMP/MCUmgr)."""
    raise HTTPException(501, "OTA firmware update not yet implemented")


# ── Slot Management ──

@app.get("/api/slots")
async def get_slots(
    slot_power: SlotPowerManager = Depends(get_slot_power),
) -> list[SlotPowerState]:
    """Get per-slot power state, card presence, voltage, and current."""
    loop = asyncio.get_running_loop()
    statuses = await loop.run_in_executor(None, slot_power.get_all_slot_status)
    return [
        SlotPowerState(
            slot_id=s.slot_id,
            power_enabled=s.power_enabled,
            card_present=s.card_present,
            bus_voltage_v=s.bus_voltage_v,
            current_a=s.current_a,
        )
        for s in statuses
    ]


@app.post("/api/slots/{slot_id}/power")
async def set_slot_power(
    slot_id: int = Depends(validate_slot_id),
    request: SlotPowerRequest = ...,
    slot_power: SlotPowerManager = Depends(get_slot_power),
):
    """Enable or disable power to a slot."""
    loop = asyncio.get_running_loop()
    if request.enabled:
        await loop.run_in_executor(None, slot_power.enable_slot, slot_id)
    else:
        await loop.run_in_executor(None, slot_power.disable_slot, slot_id)

    return {"slot_id": slot_id, "power_enabled": request.enabled}


@app.post("/api/slots/{slot_id}/reset")
async def reset_slot(
    slot_id: int = Depends(validate_slot_id),
    slot_mux: SlotMux = Depends(get_slot_mux),
):
    """Reset a card by pulsing its NRST line."""
    loop = asyncio.get_running_loop()
    await loop.run_in_executor(None, slot_mux.reset_card, slot_id)
    return {"slot_id": slot_id, "reset": True}


@app.post("/api/slots/{slot_id}/flash")
async def flash_slot(
    request: FlashRequest,
    slot_id: int = Depends(validate_slot_id),
    slot_mux: SlotMux = Depends(get_slot_mux),
):
    """Flash firmware to a card via UART bootloader."""
    loop = asyncio.get_running_loop()

    # Enter bootloader (blocking GPIO/I2C)
    await loop.run_in_executor(None, slot_mux.enter_bootloader, slot_id)

    uart_dev = slot_mux.get_uart_device()
    flasher = UartFlasher(uart_dev)

    try:
        await loop.run_in_executor(None, flasher.open)

        connected = await loop.run_in_executor(None, flasher.connect)
        if not connected:
            raise HTTPException(500, "Bootloader connection failed")

        success = await loop.run_in_executor(
            None, flasher.flash_firmware, request.firmware_path
        )
        if not success:
            raise HTTPException(500, "Flash failed")
    finally:
        await loop.run_in_executor(None, flasher.close)
        await loop.run_in_executor(None, slot_mux.exit_bootloader, slot_id)

    return {"slot_id": slot_id, "flashed": True}


# ── Bringup ──

@app.post("/api/bringup")
async def start_bringup(
    request: BringupRequest,
    state: AppState = Depends(get_app_state),
):
    """Start the autonomous bringup sequence."""
    if state.bringup_task and not state.bringup_task.done():
        raise HTTPException(409, "Bringup already in progress")

    orchestrator = BringupOrchestrator(
        slot_power=state.slot_power,
        slot_mux=state.slot_mux,
        card_manager=state.card_manager,
        firmware_path=request.firmware_path,
    )

    # Store orchestrator on app state so status endpoint can read it
    state._bringup = orchestrator
    state.bringup_task = asyncio.create_task(orchestrator.run())

    return {"status": "started"}


@app.get("/api/bringup/status")
async def get_bringup_status(
    state: AppState = Depends(get_app_state),
) -> BringupStatus:
    """Get the current bringup progress."""
    orchestrator = getattr(state, "_bringup", None)
    if orchestrator is None:
        return BringupStatus()

    r = orchestrator.result
    return BringupStatus(
        phase=r.phase,
        running=orchestrator.is_running,
        bus_voltage_v=r.bus_voltage_v,
        bus_current_a=r.bus_current_a,
        cards_found=r.cards_found,
        cards_ready=r.cards_ready,
        cards_failed=r.cards_failed,
        total_cells_passed=r.total_cells_passed,
        total_cells_failed=r.total_cells_failed,
        duration_s=r.duration_s,
        error=r.error,
        slots=[
            s for s in r.slots if s.card_present
        ] if hasattr(r, "slots") else [],
    )


@app.post("/api/bringup/abort")
async def abort_bringup(state: AppState = Depends(get_app_state)):
    """Abort the bringup sequence."""
    orchestrator = getattr(state, "_bringup", None)
    if orchestrator is None or not orchestrator.is_running:
        raise HTTPException(400, "No bringup in progress")

    await orchestrator.abort()
    return {"status": "aborted"}


# ── WebSocket: Live Measurement Stream ──

@app.websocket("/ws/measurements")
async def ws_measurements(
    websocket: WebSocket,
    interval_ms: int = 100,
):
    """
    Stream real-time cell measurements over WebSocket.

    Sends a JSON message every `interval_ms` milliseconds containing
    the latest measurement packet for each online card. Clients can
    specify a slower interval (e.g., 500ms for dashboards).

    Wire format (JSON per frame):
        {
          "timestamp": <float>,
          "cards": {
            "0": { "slot_id": 0, "cells": [...], "mcu_temp_c": ..., ... },
            ...
          }
        }
    """
    await websocket.accept()
    state: AppState = getattr(websocket.app.state, "cellsim", None)
    if state is None:
        await websocket.close(code=1011, reason="System not initialized")
        return

    interval_s = max(interval_ms, 10) / 1000.0  # floor at 10ms

    try:
        while True:
            cards_data = {}
            for slot_id, pkt in state.card_manager.measurements.items():
                cards_data[str(slot_id)] = {
                    "slot_id": pkt.slot_id,
                    "sequence": pkt.sequence,
                    "timestamp_us": pkt.timestamp_us,
                    "cells": [
                        {
                            "setpoint_v": c.setpoint_v,
                            "voltage_v": c.voltage_v,
                            "current_ma": c.current_ma,
                            "temp_c": c.temp_c,
                            "output_enabled": c.output_enabled,
                            "four_wire": c.four_wire,
                            "over_current": c.over_current,
                            "over_temp": c.over_temp,
                        }
                        for c in (pkt.cells or [])
                    ],
                    "mcu_temp_c": pkt.mcu_temp_c,
                    "vin_v": pkt.vin_v,
                    "uptime_ms": pkt.uptime_ms,
                }

            await websocket.send_json({
                "timestamp": time.time(),
                "cards": cards_data,
            })
            await asyncio.sleep(interval_s)

    except WebSocketDisconnect:
        pass
    except Exception:
        logger.exception("WebSocket measurement stream error")
        try:
            await websocket.close(code=1011)
        except Exception:
            pass


# ── SSE: Bringup Progress Stream ──

@app.get("/api/bringup/stream")
async def stream_bringup(
    state: AppState = Depends(get_app_state),
) -> StreamingResponse:
    """
    Server-Sent Events stream of bringup progress.

    Each event is a JSON-serialized BringupStatus. The stream ends
    when bringup completes or is aborted.
    """

    async def event_generator():
        prev_phase = None
        while True:
            orchestrator = getattr(state, "_bringup", None)
            if orchestrator is None:
                yield _sse_event({"phase": "idle", "running": False})
                return

            r = orchestrator.result
            status = BringupStatus(
                phase=r.phase,
                running=orchestrator.is_running,
                bus_voltage_v=r.bus_voltage_v,
                bus_current_a=r.bus_current_a,
                cards_found=r.cards_found,
                cards_ready=r.cards_ready,
                cards_failed=r.cards_failed,
                total_cells_passed=r.total_cells_passed,
                total_cells_failed=r.total_cells_failed,
                duration_s=r.duration_s,
                error=r.error,
                slots=[s for s in r.slots if s.card_present]
                if hasattr(r, "slots") else [],
            )

            yield _sse_event(status.model_dump())

            # Stop streaming when bringup finishes
            if not orchestrator.is_running:
                return

            await asyncio.sleep(0.5)

    return StreamingResponse(
        event_generator(),
        media_type="text/event-stream",
        headers={
            "Cache-Control": "no-cache",
            "Connection": "keep-alive",
            "X-Accel-Buffering": "no",
        },
    )


def _sse_event(data: dict) -> str:
    """Format a dict as an SSE event string."""
    import json
    return f"data: {json.dumps(data)}\n\n"


# ── Entry Point ──

def run():
    """Entry point for `cellsim` CLI command."""
    import uvicorn

    logging.basicConfig(
        level=logging.INFO,
        format="%(asctime)s %(levelname)-8s %(name)s: %(message)s",
    )
    uvicorn.run(app, host="0.0.0.0", port=8000)

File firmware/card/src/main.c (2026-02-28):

/*
 * CellSim Card Firmware
 * =====================
 * Zephyr RTOS application for the CellSim v2 cell card.
 *
 * Architecture:
 *   - 100 Hz control loop: reads ADCs, updates DACs, runs calibration
 *   - UDP streaming: sends measurement packets to CM5 at 100 Hz
 *   - TCP command server: receives commands from CM5
 *   - mDNS: advertises as cellsim-card-{slot_id}.local
 *   - MCUmgr/SMP: OTA firmware update over UDP
 *   - Self-test: BIST on all 8 cells at boot + on demand
 *   - Watchdog: hardware IWDG + CM5 heartbeat monitor
 *   - Health: internal temp, Vrefint, input voltage in every packet
 *
 * I2C topology (per card):
 *   I2C1 -> TCA9548A -> [ISO1640 -> cell devices] x 4  (cells 0-3)
 *   I2C2 -> TCA9548A -> [ISO1640 -> cell devices] x 4  (cells 4-7)
 *
 * Per-cell devices (on isolated side):
 *   - MCP4725 DAC ×2 (buck + LDO setpoints, via I2C)
 *   - ADS131M04 ADC (4ch simultaneous, via SPI + ISO7741 isolator)
 *   - TCA6408 GPIO expander (relay, enable, load switch, 2/4-wire, via I2C)
 *   - TMP117 temperature sensor (via I2C)
 *
 * Backplane signals:
 *   - USART1 (PA9 TX, PA10 RX): remote debug/flash via CM5 slot mux
 *   - BOOT0: ROM bootloader entry (pulled low on card, driven by CM5 mux)
 *   - NRST: reset (pulled high on card, driven by CM5 mux)
 *   - Slot ID: 4 GPIO inputs (active-low, coded by backplane resistors)
 *   - Input voltage: ADC3 via 100k/10k divider from 24V bus
 */

#include <zephyr/kernel.h>
#include <zephyr/drivers/gpio.h>
#include <zephyr/logging/log.h>

#include "card_id.h"
#include "cell.h"
#include "led.h"
#include "self_test.h"
#include "watchdog.h"
#include "health.h"
#include "network.h"

LOG_MODULE_REGISTER(cellsim, LOG_LEVEL_INF);

/* Firmware version (embedded in mDNS TXT record and self-test response) */
#define FW_VERSION_MAJOR 2
#define FW_VERSION_MINOR 0
#define FW_VERSION_PATCH 0

/**
 * Read slot ID from 4 GPIO pins (active-low, coded by backplane resistors).
 * Returns 0-15 for valid slots.
 */
static uint8_t read_slot_id(void)
{
    /* TODO: read 4 GPIO pins and decode slot ID
     * Slot ID pins are active-low: 0 = pull-down on backplane, 1 = pull-up
     * Binary encoding: slot_id = ~(GPIO3:GPIO0) & 0x0F
     */
    return 0; /* Placeholder: slot 0 */
}

int main(void)
{
    LOG_INF("CellSim card firmware v%d.%d.%d starting...",
            FW_VERSION_MAJOR, FW_VERSION_MINOR, FW_VERSION_PATCH);

    /* Read slot ID from backplane resistor coding */
    uint8_t slot_id = read_slot_id();
    LOG_INF("Slot ID: %d", slot_id);

    /* Read card identity EEPROM (24AA025E48 on I2C3) */
    int ret = card_id_init();
    if (ret != 0) {
        LOG_WRN("Card identity EEPROM read failed: %d (using fallback ID)", ret);
    }

    /* Initialize status LED and set booting color (blue) */
    ret = led_init();
    if (ret != 0) {
        LOG_WRN("Status LED init failed: %d (continuing without LED)", ret);
    } else {
        led_set_status_booting();
    }

    /* Initialize health monitoring (ADC3: internal temp, Vrefint, input voltage) */
    ret = health_init();
    if (ret != 0) {
        LOG_WRN("Health monitoring init failed: %d (continuing)", ret);
    }

    /* Initialize watchdog (hardware IWDG + CM5 heartbeat monitor) */
    ret = watchdog_init();
    if (ret != 0) {
        LOG_ERR("Watchdog init failed: %d", ret);
        /* Continue anyway — watchdog is important but not fatal */
    }

    /* Run self-test on all 8 cells */
    struct self_test_result st_result;
    ret = self_test_run(&st_result);
    if (ret != 0) {
        LOG_ERR("Self-test failed to run: %d", ret);
    } else if (!st_result.all_passed) {
        LOG_WRN("Self-test: some cells FAILED (MCU: %.1f°C, Vin: %.1fV)",
                (double)st_result.mcu_temp_celsius,
                (double)st_result.input_voltage);
        led_set_status_warning();
    } else {
        LOG_INF("Self-test: ALL PASSED (MCU: %.1f°C, Vin: %.1fV)",
                (double)st_result.mcu_temp_celsius,
                (double)st_result.input_voltage);
        led_set_status_ok();
    }

    /* Initialize cell control HAL (DACs, ADCs, GPIO expanders) */
    ret = cell_init();
    if (ret != 0) {
        LOG_ERR("Cell HAL init failed: %d", ret);
        /* Non-fatal: some cells may still work */
    }

    /* Initialize network services (mDNS, TCP, UDP) */
    ret = network_init(slot_id);
    if (ret != 0) {
        LOG_ERR("Network init failed: %d", ret);
        return ret;
    }

    /* Start TCP command server thread */
    ret = network_start_cmd_server();
    if (ret != 0) {
        LOG_ERR("Failed to start command server: %d", ret);
    }

    /* Start UDP measurement streaming + 100 Hz control loop */
    ret = network_start_meas_stream();
    if (ret != 0) {
        LOG_ERR("Failed to start measurement stream: %d", ret);
    }

    LOG_INF("CellSim card firmware initialized (slot %d)", slot_id);

    /* Main thread: nothing more to do, work happens in spawned threads.
     * Zephyr idle thread handles power management. */
    return 0;
}

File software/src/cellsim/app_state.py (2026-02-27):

"""
CellSim v2 — Application State

Central state container stored on FastAPI's app.state.
Provides typed access to all subsystem managers and avoids global singletons.
"""

from __future__ import annotations

import asyncio
import logging
from dataclasses import dataclass, field
from functools import partial
from typing import Any

from cellsim.card_manager import CardManager
from cellsim.slot_power import SlotPowerManager
from cellsim.slot_mux import SlotMux
from cellsim.models import NUM_SLOTS

logger = logging.getLogger(__name__)


@dataclass
class AppState:
    """Typed container for all subsystem managers."""

    slot_power: SlotPowerManager = field(default_factory=SlotPowerManager)
    slot_mux: SlotMux = field(default_factory=SlotMux)
    card_manager: CardManager = field(default_factory=CardManager)
    bringup_task: asyncio.Task | None = None
    _executor_loop: asyncio.AbstractEventLoop | None = None

    async def startup(self) -> None:
        """Initialize all hardware managers."""
        self._executor_loop = asyncio.get_running_loop()

        # Initialize slot power (blocking I2C calls → run in executor)
        await self._run_sync(self.slot_power.init)

        # Initialize slot mux (shares I2C bus from slot_power)
        await self._run_sync(self.slot_mux.init, self.slot_power._bus)

        # Start card discovery and measurement listener
        await self.card_manager.start_discovery()
        await self.card_manager.start_measurement_listener()

        logger.info("AppState initialized: %d slots configured", NUM_SLOTS)

    async def shutdown(self) -> None:
        """Clean up all managers."""
        if self.bringup_task and not self.bringup_task.done():
            self.bringup_task.cancel()
            try:
                await self.bringup_task
            except asyncio.CancelledError:
                pass

        await self._run_sync(self.slot_mux.close)
        await self._run_sync(self.slot_power.close)
        logger.info("AppState shutdown complete")

    async def _run_sync(self, fn, *args, **kwargs) -> Any:
        """Run a blocking function in the default executor."""
        loop = self._executor_loop or asyncio.get_running_loop()
        if kwargs:
            return await loop.run_in_executor(None, partial(fn, *args, **kwargs))
        return await loop.run_in_executor(None, partial(fn, *args))

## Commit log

2025-05-07 fix current rounding issue
2025-08-19 add check for input voltage to be within valid range before calibrating
2025-08-19 add fast calibrate
2025-11-25 Update README with CellSim API documentation
    Added API documentation for CellSim functionality including enabling outputs, setting voltages, measuring voltages, and using load switch.
2026-02-26 Add manufacturing section to README
    Added manufacturing instructions and a note about the isolated regulator.
2026-02-26 Update README with manufacturing instructions
    Added note about depopulating the isolated regulator during manufacturing.
2026-02-27 Add TI ADS131M04 4-channel 24-bit SPI ADC package
    Driver module for the Texas Instruments ADS131M04 simultaneous-sampling
    delta-sigma ADC. Includes dual power rails (AVDD/DVDD), SPI interface,
    4 differential input channels via DifferentialPair, and reference bypass
    capacitor. Both default and usage targets build successfully.
    [C0402_L1.0-W0.5-H0.5.step, R0402_L1.0-W0.5-H0.4.step]
2026-02-27 Add TI ISO7741 quad-channel digital SPI isolator package
    Driver module for the Texas Instruments ISO7741 digital isolator configured
    for SPI bus isolation. Three forward channels (SCLK, MOSI, CS) and one
    reverse channel (MISO) with separate power domains on each side. Includes
    enable pullups and 100nF decoupling per side. Both targets build cleanly.
    [C0402_L1.0-W0.5-H0.5.step, R0402_L1.0-W0.5-H0.4.step]
2026-02-27 Add TI TPSM863257 per-cell integrated buck converter package
    Driver module for the Texas Instruments TPSM863257 integrated power module
    (3V-17V input, 0.6V-5.5V output, 3A). Includes feedback divider for ~5V
    default output, input/output decoupling caps, and power-good pullup.
    Integrated inductor — no external magnetics needed. Both targets build.
    [C0402_L1.0-W0.5-H0.5.step, C0805_L2.0-W1.3-H1.3.step, QFN-7_L4.0-W3.3_TPSM863257RDXR.STEP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]
2026-02-27 Add TI TPSM84209 card-level integrated buck converter package
    Driver module for the Texas Instruments TPSM84209 integrated power module
    (4.5V-28V input, 1.2V-6V output, 2.5A). Designed for 24V backplane to 5V
    card-level conversion. Includes feedback divider (52.3k/10k for ~5V),
    input/output decoupling, and EN pullup to VIN. Both targets build.
    [C0402_L1.0-W0.5-H0.5.step, C0805_L2.0-W1.3-H1.3.step, R0402_L1.0-W0.5-H0.4.step]
2026-02-27 Add Microchip 24AA025E48 I2C EEPROM with EUI-48 MAC address package
    Driver module for the Microchip 24AA025E48T-I/OT, a 2Kbit I2C EEPROM with
    factory-programmed unique EUI-48 MAC address. Includes I2C pull-ups (4.7k),
    100nF decoupling, and address pins defaulting to GND (address 0x50).
    Both default and usage targets build successfully.
    [C0402_L1.0-W0.5-H0.5.step, R0402_L1.0-W0.5-H0.4.step, SOT-23-6_L2.9-W1.6-H1.5-LS2.8-P0.95.step]
2026-02-27 Add high-side-switch package and update .gitignore
    Include the existing high-side-switch P-FET power switch package and add
    layouts/ to .gitignore (auto-generated by atopile builds).
    [R0402_L1.0-W0.5-H0.4.step]
2026-02-27 cellsimv2 cleanup
    [C0402_L1.0-W0.5-H0.5.step, C0603_L1.6-W0.8-H0.8.step, C0805_L2.0-W1.3-H1.3.step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]
2026-02-27 Update spec with per-slot relay power switching architecture
    Replace E-stop bus relay + P-FET high-side switch with 16x per-slot
    Omron G5Q-1A4 DC24 relays. E-stop button cuts coil supply to all
    relays simultaneously. Add MCP23017 + N-FET drive circuit, INA3221
    per-slot current monitoring, INA228 bus monitor, and full backplane
    I2C bus map.
2026-02-28 Add per-slot relay power switching to backplane design
    Replace high-side FET switches with 16x Omron G5Q-1A4 DC24 SPST-NO
    relays for per-slot power control. Each relay includes N-FET driver,
    flyback protection, and indicator LED via LogicLevelRelayBase.
    E-stop architecture: NC button cuts relay coil supply (24V_COIL),
    de-energizing all relays simultaneously. Base board stays powered.
    Key changes:
    - Rewrite SlotManager: 16x relay array, 3x MCP23017 GPIO, 6x INA3221
    current monitors behind TCA9548A mux
    - Add relays-local/ package (trimmed atopile/relays fork with G5Q part)
    - Update ato.yaml: remove high-side-switch dependency
    [RELAY-TH_G5Q-1A4.step, SOT-23-3P_L2.9-W1.3-H1.0-LS2.4-P0.95.step]
2026-02-28 Add SK6805-EC20 status LED driver and update firmware for ADS131M04 ADC
    LED subsystem:
    - New led.c/led.h: WS2812-compatible driver using Zephyr led_strip API
    - Device tree: ws2812-gpio binding on PF13 with GRB color mapping
    - Kconfig: LED_STRIP + WS2812_STRIP_GPIO enabled
    - Boot sequence: blue (booting) → green (OK) / yellow (warning) → red (fault)
    - Watchdog safe state sets LED to red on heartbeat timeout
    Firmware updates (pre-existing working tree changes):
    - ADS131M04 SPI ADC driver (cell.c/h, self_test.c)
    - Card identity via 24AA025E48 EEPROM (card_id.c/h)
    - Network/protocol updates for new measurement format
    - Elec: cell-card ato updates, ADS131M04 package yaml, capacitor part
    Co-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
    [C0805_L2.0-W1.3-H1.3.step]
2026-03-11 adhd commit
    [C0402_L1.0-W0.5-H0.5.step, C0603_L1.6-W0.8-H0.8.step, C0805_L2.0-W1.3-H1.3.step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]
